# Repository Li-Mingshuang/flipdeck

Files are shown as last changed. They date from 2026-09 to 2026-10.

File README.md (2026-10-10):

# flipdeck —— 让手机变掌机的翻盖手柄壳（可翻转托盘）

```
翻开 = 3DS 形态：手机当上屏，下面是实体摇杆 + 按键
合上 = 普通手机：托盘翻 180°，手机屏幕朝上，按键被盖住
```

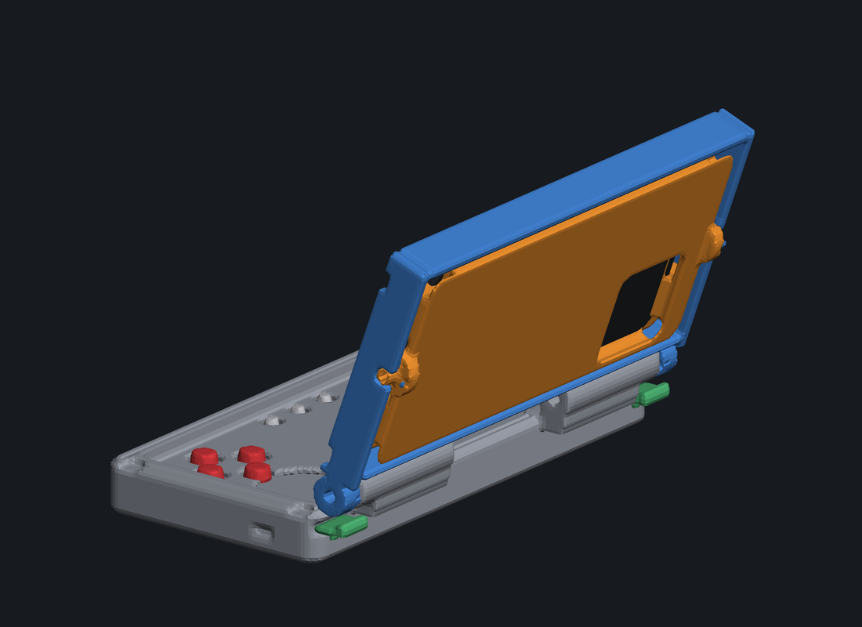
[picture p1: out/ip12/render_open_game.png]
展开游戏形态






**👉 [在线 3D 交互演示](https://li-mingshuang.github.io/flipdeck/)** —— 拖动看三种形态、拉滑块看托盘翻转、**还能直接用键盘玩手机屏幕上那个小游戏**（按哪个键，3D 模型上对应的键帽就按下去、摇杆就跟着摆）。

---

## 这是什么

一个**参数化 3D 结构方案**：给 iPhone 12（以及所有 ≤157×71.5mm 的 6.1"~6.3" 非 Max 机型）做的翻盖手柄壳。核心是一个**双平行轴机构**：

| 轴 | 位置 | 作用 |
|---|---|---|
| 合盖轴 θ | 后缘 | 翻开 / 合上，110° 是游戏角 |
| 托盘翻转轴 φ | 盖框内中线（沿 X） | 把手机连托盘翻 180°，屏幕从朝内变朝外 |

三种形态，一个动作切换：

| 形态 | θ / φ | 效果 |
|---|---|---|
| 展开游戏 | 110° / 0° | 手机当上屏（屏幕朝玩家），底座是摇杆 + 按键 |
| 合盖收纳 | 0° / 0° | 手机屏朝内被盖包住，按键也朝内，全保护 |
| 手机模式 | 0° / 180° | 手机屏朝上露出，按键被盖盖住，直接当普通手机用 |

## 三个关键设计（也是这个形态能成立的原因）

1. **托盘轴放在托盘板的中面上** → 翻转 180° 后托盘仍占同一层空间，只有手机从盖内侧换到盖外侧。否则要么盖变厚，要么合盖时手机撞底座。
   托盘还带一圈 **7.4mm 围边**（比手机屏幕高 0.7mm）：φ=0 时朝内、φ=180 时朝外，所以**两个方向手机都是"嵌"在托盘里的**，不会出现"一整块贴在框背面的板砖"。围边在 ±X 两端各开一个手指缺口方便取手机；围边留在托盘 160×74.5 轮廓内，翻转扫掠半径 37.85mm（横梁在 39mm，仍留 1.15mm）。
2. **铰链凸耳全部走左右两侧**（`|x| ∈ [80, 88.5]`）→ 托盘/手机翻转时扫出半径 37.9mm 的圆，盖的中间区域不能有任何腹板。（第一版腹板在中间，直接被扫掠圆撞掉，是靠数值检查抓出来的。）
3. **控制件全部沉进井里** → 合盖时手机屏幕的平面就是底座顶面，所以摇杆要沉进口袋、键帽要嵌进孔里（现在净空 3.5mm）。

## 已验证的东西（不是嘴上说说）

所有几何都是 SDF 参数化建模 + 数值验证，`python build.py` 一键复现：

| 检查 | 结果 |
|---|---|
| 9 个打印件网格 | **全部水密**（边界边 0、非流形边 0），直接可切片 |
| 13 项装配姿态间隙 | **全部无干涉** |
| 托盘翻转全程扫描（φ 0→180 每 10°） | 最坏 **+0.15mm**（就是 Ø6 轴颈在 Ø6.3 轴承孔里的设计间隙） |
| 合盖游戏位：手机屏幕 ↔ 最高控制件 | **+2.5mm** 净空 |
| 合盖手机模式：deck ↔ 手机 | **+8.8mm** |
| 整机厚度 | 合盖游戏 **34.1mm**；手机模式 **42.4mm**；**拔掉底座当日常壳 22.5mm** |

**日常模式**：拧下铰链的 M4 螺杆 → 取下带按键的底座 → 剩下盖框 + 托盘 + 手机 = **22.5mm 厚**的保护壳，屏幕朝上正常用。这是这个结构天然的"两用"方式，不需要额外零件（建议用 M4 手拧螺钉或插销，方便随时拆装）。

<details>
<summary>过程中修掉的真问题（点开看）</summary>

- 间隙检测公式用 `min(dA+dB)` 会**假阳性** → 改用 `min max(dA, dB)`
- 托盘位姿写成 `R·p + pivot` 会让托盘整体平移 51mm，导致 φ=180° 的所有检查数字全是假的
- 密封条槽外缘与外壳上收边在圆角处相交 → 会切出 0.3mm 薄片（已改成同心内缩，并写进断言）
- 体素网格化时零件平面正好落在采样平面上会产生歧义单元 → 非流形边；加"自动搜索采样相位"后 9 件全水密
- 画 PCB 时发现 ABXY 上排 / 十字键上臂的开关焊盘压进摇杆口袋的孔里 → 按键簇前移 3mm

</details>

## 快速开始（做一台能玩的原型）

| 步 | 做什么 | 花费 |
|---|---|---|
| 1 | **打印**：先只打 `cradle.stl`（首件验手机），再打 `deck` + `lid` | ¥30–60 起（代打） |
| 2 | **买件**：ESP32-S3 SuperMini + 2×摇杆模块 + 11 个 6×6×2.0 贴片开关 + 五金 | ~¥80–140 |
| 3 | **刷固件**：`firmware/flipdeck_gamepad/flipdeck_gamepad.ino`（Arduino IDE，改引脚即可） | ¥0 |
| 4 | 焊线 → 装壳 → 手机蓝牙配对 `flipdeck` → 开玩 | ¥0 |

- 打印下单话术 + 首件检查单：**[ORDER_KIT.md](ORDER_KIT.md)**（可直接复制给代打）
- 采购清单 / 引脚表 / 接线 / 固件说明：**[ELECTRONICS.md](ELECTRONICS.md)**、**[firmware/README.md](firmware/README.md)**
- 打印参数 / 装配顺序 / 分期计划 / 风险：**[DIY_GUIDE.md](DIY_GUIDE.md)**
- 进度、决策记录、升级待办：**[PROGRESS.md](PROGRESS.md)**

> **不需要画 PCB**：摇杆直接拧进底座（口袋里有 Ø28 分布圆的 M2 自攻孔），主控拧在底座的 PCB 柱上，11 个开关用打印的开关架定位（`switch_frame.stl`）。

## 在线 3D 演示

- 线上：<https://li-mingshuang.github.io/flipdeck/>（GitHub Pages，源 = `docs/`）
- 本地：

```bash
python -m http.server 8010
# 浏览器打开 http://127.0.0.1:8010/web/flipdeck_viewer.html
```

演示页是**零依赖**的（自己写的 WebGL 渲染器，不用 CDN）：拖滑块改 θ/φ、一键三形态、播放翻转动画、隐藏部件看内部、**日常模式一键看**（拔掉底座的样子）、换屏幕内容（可玩的游戏 / 主屏幕 / 你自己的图 / 灭屏）、CRT 扫描线滤镜。
**键盘能直接玩屏幕里的游戏**（两套：横版跑酷 + 伪 3D 赛车），同时 3D 模型上的键帽会按下去、十字键会跷、摇杆会摆；鼠标也能直接拖摇杆帽。
机构常数由 `web/public_params.json`（`web_export.py` 生成）注入，页面不会和 CAD 参数漂移；矩阵数学用 `web/verify_matrix.js` 与 Python 的 `poses.pose` 对过答案，四个姿态偏差 ≤0.0005mm。

## 🏆 排行榜 Top 10

> 在演示页里玩完小游戏（**跑酷 / 俄罗斯方块 / 打砖块 / 贪吃蛇 / Flappy**），点「提交成绩」会开一个预填好的 GitHub Issue；Actions 自动汇总到这里，也会画在演示页的手机屏幕上（屏幕下拉框选「🏆 排行榜（实时）」）。同一玩家每款游戏只记最好成绩。

<!-- LEADERBOARD:BEGIN -->
## 🎮 跑酷（`run`）

_还没有成绩 —— 来占个第一？_

## 🎮 俄罗斯方块（`tetris`）

_还没有成绩 —— 来占个第一？_

## 🎮 打砖块（`break`）

_还没有成绩 —— 来占个第一？_

## 🎮 贪吃蛇（`snake`）

_还没有成绩 —— 来占个第一？_

## 🎮 Flappy（`flappy`）

_还没有成绩 —— 来占个第一？_

_最后更新：2026-10-10 09:51（UTC）_
<!-- LEADERBOARD:END -->

## 模块化：换个底座就变形态

**铰链接口就是模块标准**（铰链销孔、凸耳位置、贴合面高度 19mm、磁铁位、密封槽都固定不变）。拔掉 M4 销 → 取下底座 → 换上另一个底座 → 插回销，10 秒完成；盖子、托盘、手机全都不用动。

| 底座 | 内容 | 用途 |
|---|---|---|
| `deck`（手柄底座） | 2 摇杆 + 11 按键 + 打印开关架 | 玩游戏 |
| `deck_keyboard`（键盘底座） | 一个**买来的迷你蓝牙键盘模块**（约 150×60×7.5mm，自带电池/蓝牙/充电口）的舱位 | **vibecoding**：手机在上盖当屏幕、键盘在下座 = 迷你笔记本 |
| 不装底座（日常） | 只剩盖框 + 托盘 + 手机 | 当普通保护壳（22.5mm 厚） |

键盘底座设计要点：舱体 152.4×62.4，模块放进去后**键面比边缘低 0.5mm**；前缘 0.8mm 挡边防倒置掉出；左侧壁开 14×6 口给模块插线充电；底部掏空省料。不需要触摸板（手机屏幕本身就是触摸屏），也不需要自研电路（键盘模块自带 BLE）—— **只需要打印一个底座**。

演示页里点「底座：手柄 / 键盘」可以直接切换看两种形态。

## 仓库结构

```
flipdeck-cad/
├─ flipdeck/            内核：params(参数) sdf(SDF内核) parts(零件) poses(位姿+间隙检查)
│                       meshlib(SDF→水密网格/STL) render(纯 numpy 软件渲染器)
├─ firmware/            ESP32-S3 BLE 手柄固件 + 烧录/标定说明
├─ web/                 交互式 3D 演示（WebGL，零依赖）+ 轻量 STL
├─ docs/                GitHub Pages（= web 的打包产物，由 make_docs.py 生成）
├─ out/stl/             **9 个打印件 STL**（全部水密）
├─ out/ip12/            iPhone 12 版渲染图（含 contact_sheet 总览拼图）
├─ out/pcb/             PCB 板框（DXF/SVG/PNG）+ 板级自检报告
├─ build.py             SDF→网格→STL + 渲染 + 报告（一键复现）
├─ check_poses.py       装配干涉检查
├─ pcb_outline.py       板框生成 + 板级自检
├─ web/verify_*.js      **没浏览器也能验证网页**（见下）
├─ web_export.py        导出网页用轻量 STL
├─ make_docs.py         生成 docs/（Pages）
├─ status.py            刷新 PROGRESS.md 的状态块
└─ ORDER_KIT.md / DIY_GUIDE.md / ELECTRONICS.md / PROGRESS.md / README.md
```

一键复现：`python build.py --render-dir ip12`（STL + 渲染 + 报告，约 6 分钟）。

**没浏览器也能验证网页**（本项目的所有前端改动都靠这套兜底，因为写代码的模型看不到画面）：
- `node web/verify_matrix.js` —— 机构矩阵与 Python 的 `poses.pose` 对答案（四个姿态偏差 ≤0.0005mm）
- `node web/verify_framing.js` —— 自动取景是否把所有零件完整包进画面（逐姿态算画面占用率）
- `node web/verify_runtime.js` —— 用 DOM/WebGL 桩把页面 JS 真跑一遍：逐条跑五个游戏、排行榜屏幕、姿态切换、提交按钮…并统计 `drawArrays` 次数，专门抓"打开就黑屏"这类加载期异常

## 换机型

`deck` 和 `lid` 的几何**完全不引用手机参数** —— 换手机只换托盘这一个件。托盘外廓 160×74.5 是"接口标准"，可装上限 **157 × 71.5mm**（6.1"~6.3" 非 Max 机型通用）；Pro Max / Plus 那档（77.6~78.1mm 宽）需要放大托盘并连锁放大盖框和底座。改 `flipdeck/params.py` 里的 `PHONES` 表 + `DEFAULT_PHONE`，然后 `python build.py` 即可，`sanity()` 会重新断言所有余量。

## 已知取舍

- **合盖手机模式相机会被盖挡住**（后摄贴着托盘板），要合盖拍照需要托盘轴偏心 + 开相机通孔
- **没有硬限位**：0°/110°/180° 靠凸点 + 摩擦自锁，防不住暴力过转
- **合盖 34–42mm 厚**：这是"合盖还要能当手机用"的物理代价；**日常用就拧下螺杆取走底座（22.5mm）**，想要更薄只能改架构（控制模块做成磁吸可拆）
- 手机固定靠托盘挡墙 + 沉台（正常使用不会掉），倒甩/装兜需要再加磁铁或 TPU 卡爪

## 许可证

- 代码（Python / 固件 / 网页）：**MIT**
- 硬件设计文件（STL、Pages 页面、生成的几何）：**CC BY 4.0**，署名注明 `flipdeck` 及本仓库链接

详见 [LICENSE](LICENSE)。

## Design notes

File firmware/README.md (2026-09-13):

# flipdeck 固件：烧录与标定

文件：`flipdeck_gamepad/flipdeck_gamepad.ino`（一个文件，Arduino IDE 直接打开）
作用：把底座的 2 个摇杆 + 11 个按键，做成标准 **BLE HID 游戏手柄**，iPhone / Android / PC 直接配对。

---

## 1. 装环境（一次性，15 分钟）

1. 装 **Arduino IDE 2.x**
2. 加 ESP32 开发板支持：`文件 → 首选项 → 附加开发板管理器网址` 填
   `https://espressif.github.io/arduino-esp32/package_esp32_index.json`
   → `工具 → 开发板 → 开发板管理器` 搜 `esp32` 安装 **2.0.x（推荐 2.0.17）**
   > ⚠️ **别用 3.x**：BLE API 变过，`ESP32 BLE Gamepad` 库在 3.x 上大概率编不过。
3. 装库：`工具 → 管理库` 搜 **ESP32 BLE Gamepad**（作者 lemmingDev）安装
   （装不上就从 GitHub 下 ZIP，用"从 ZIP 安装库"）

## 2. 烧录

1. 打开 `flipdeck_gamepad.ino`
2. 开发板选 **ESP32S3 Dev Module**；`USB CDC On Boot = Enabled`（不然串口没输出）
3. USB 插上，选对应串口 → 点上传
4. 串口监视器 115200，应看到：
   ```
   [flipdeck] booting ...
   [flipdeck] 标定摇杆中点：请松手
   [flipdeck] center  L=(2043,2051)  R=(2038,2049)
   [flipdeck] BLE name = flipdeck，等待配对…
   ```

## 3. 配对

- **iPhone 12**：`设置 → 蓝牙` → 找到 **flipdeck** → 点连接（会显示成"游戏手柄"）
- 验证：装个手柄测试 App（或直接在 Delta 模拟器里绑定按键）
- 连不上时：蓝牙里"忽略此设备"，开发板断电重上；iOS 会缓存旧的 BLE 设备名

## 4. 标定（拿到实物后做一次，5 分钟）

固件默认会在**开机时自动取摇杆中点**（开机那一秒别碰摇杆）。上下限和方向按需要微调：

1. 把 `#define DEBUG_SERIAL 1`，重新烧录，串口会每 200ms 打印原始值：
   ```
   raw LX=2043 LY=2051 RX=2038 RY=2049 | hat=0 | A=0 B=0 X=0 Y=0
   ```
2. 把摇杆推到底，记下 **最小/最大原始值**，改这两行：
   ```c
   #define ADC_MIN_RAW   200     // 推到底的最小值（比实测再往里留 50~100 更稳）
   #define ADC_MAX_RAW   3900    // 推到底的最大值
   ```
3. 方向反了 → 改 `INVERT_LX / LY / RX / RY`（左右反了改 X，上下反了改 Y）
4. 中心抖/漂 → 加大 `DEADZONE_PCT`（默认 6）或加大 `FILTER_SHIFT`（默认 2）
5. 都调好后把 `DEBUG_SERIAL` 改回 0，重新烧录

## 5. 按键对应关系（想换布局改配置区）

| 底座上的键 | GPIO | HID 编号 |
|---|---|---|
| A / B / X / Y | 6 / 7 / 8 / 9 | 1 / 2 / 3 / 4 |
| 十字键 | 12 / 13 / 14 / 15（上/下/左/右） | 帽子开关（Hat），不是独立按键 |
| Select / Start / Home | 17 / 16 / 18 | 9 / 10 / 13 |
| L1 / R1（肩键） | 21 / 38 | 5 / 6 |
| L3 / R3（摇杆按下） | 39 / 40 | 11 / 12 |
| 左摇杆 X / Y | 1 / 2 | 左摇杆轴 |
| 右摇杆 X / Y | 3 / 4 | 右摇杆轴 |
| 电池采样（可选） | 11 | 需分压 100k/100k，`REPORT_BATTERY 1` 才启用 |

> 日式手感（A/B 对调、X/Y 对调）→ 只改 `BTN_A`/`BTN_B`/`BTN_X`/`BTN_Y` 四个数字。
> 十字键用**帽子开关**上报（iOS 上游戏识别最正常）；如果你的游戏把十字键当按钮（1/2/3/4 那类），告诉我，我把 4 个开关改成独立按键上报。

## 6. 常见编译/烧录问题

| 现象 | 原因 / 处理 |
|---|---|
| `setAxes` 参数个数不对 | 库版本差异：把 `AXES_API` 改成 `6`（旧版没有 rudder），或按文件里注释改成 `setLeftThumb/setRightThumb/setHat1` |
| `setBatteryLevel` 未定义 | 老库没有这方法 → 保持 `REPORT_BATTERY 0` |
| BLE 库编译报 `NimBLE`/`BLEDevice` 相关错 | 开发板核心是 3.x → 降到 2.0.17 |
| 上传卡在 `Connecting...` | 按住 BOOT 再点上传；或换根数据线（很多线只能充电） |
| 串口没输出 | `USB CDC On Boot` 没开 |
| 配对了但游戏不认 | 先用测试 App 确认手柄在线；游戏本身不支持手柄的话，换有线也没用 |
| 摇杆一直往一边跑 | 中点没标定好 → 重开一次（开机时松手），或手动改 `ADC_CENTER_RAW` |

## 7. 接线对照（焊之前对一遍）

```
摇杆模块 5 针：VCC→3V3   GND→GND   X→对应 ADC 脚   Y→对应 ADC 脚   SW→L3/R3 脚
11 个开关    ：一端→GPIO，另一端→公共 GND（开关架上的横向总线槽就是干这个的）
主控供电     ：USB-C（原型阶段直接插线玩）；后期接锂电池 + TP4056
VBAT 采样（可选）：电池正极 → 100k → GPIO11 → 100k → GND
```

> 引脚表与 `ELECTRONICS.md` §7 一致，两边同时改就不会错。

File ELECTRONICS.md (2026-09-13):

# flipdeck 电子方案：能买现成吗？怎么装？

> 一句话回答：**电路全部能买现成的，一个零件都不用自己设计**；只有"翻转手柄壳"这个结构没有现成的（那就是我们做的）。
> 你的机器是 **iPhone 12（Lightning 口）**，所以只能走**蓝牙 BLE**，有线 USB 这条最省事的路走不通（下详）。

---

## 1. 哪些能买现成

| 环节 | 现成度 | 说明 |
|---|---|---|
| 翻转壳本体 | ✗ 没有 | 这就是本项目做的东西（STL 已出） |
| 主控 | ✔ 完全现成 | ESP32-S3 / nRF52840 开发板，¥25–70，BLE HID 手柄固件是开源的 |
| 摇杆 | ✔ 完全现成 | 现成的摇杆模块（碳膜或霍尔），带排线，¥5–15/个 |
| 按键 | ✔ 完全现成 | 贴片/插件轻触开关，¥0.1–0.5/个 |
| 电池 + 充电 | ✔ 完全现成 | 3.7V 软包 + TP4056/IP5306 充电小板，¥25–40 |
| 磁铁 / 螺丝 / 泡棉 | ✔ 完全现成 | 淘宝任意 |
| PCB | ⭕ 可以不打 | 第一版**飞线/杜邦线**就能跑通；要打板的话板框我已经生成好 |
| 固件 | ✔ 现成开源 | `ESP32-BLE-Gamepad`（lemmingDev）等，改改引脚映射即可 |

**完全可以"零电路设计"做出第一台原型**：开发板 + 摇杆模块 + 开关 + 电池，用线连起来塞进壳里。

## 2. 四条路线（按"省事 → 折腾"排）

| 路线 | 买什么 | 成本 | 说明 |
|---|---|---|---|
| **0：验证游戏认不认手柄** | 你已有的蓝牙手柄（没有就买一个 —— 反正后面能当供体） | ¥0–100 | 测的是"**游戏/模拟器认不认手柄**"，跟蓝牙/有线无关。已有手柄或已知支持 → **直接跳过** |
| **1：拆蓝牙手柄当供体（推荐原型走这条）** | 一个便宜的蓝牙手柄 ¥60–100 | **最低** | **iOS 原生支持标准蓝牙手柄（Xbox/PS4/PS5/Switch Pro），不需要 MFi**。拆出它的主板/摇杆/电池/充电口/电源开关全用上，你只要把 11 个开关焊到它的按键矩阵（万用表量行列）。**不用写固件、不用转接头、结构不用改** |
| **2：ESP32-S3 自建** | SuperMini + 摇杆模块 ×2 + 开关 + 电池 + 充电板 | ¥100–150 | 灵活可控，但要改固件引脚映射。适合供体摇杆尺寸不合适、或想完全自己掌控时 |
| **3：打板集成** | 上面那些 + 自己画板（嘉立创 5 片 ¥5–30） | +¥30 | 用我给的 DXF 板框。想批量/想好看再走 |

> ⚠️ 路线 1 唯一要注意的：**供体的摇杆尺寸不一定正好塞进我设计的 Ø32 口袋**。选定供体后量一下摇杆模块的直径和高度告诉我，我改口袋直径或出个转接环（几分钟的事）。

### 两条路线的真实成本与取舍（国内价）

| | 实际花费 | 要逆向按键矩阵 | 要刷固件 | 摇杆要不要挪位置 |
|---|---|---|---|---|
| **拆供体手柄** | **¥50–90**（带 2 摇杆的拉伸蓝牙手柄就这个价） | ✔ 万用表量行列 | ✗ | ✔ 从供体板上拆下来焊线 |
| **散件自建**（摇杆模块 + ESP32） | **¥40–70** | ✗ | ✔（代码我可以给） | ✗ 现成模块直接塞口袋 |

两条路总价接近：**会动烙铁的话，自建其实更干净**（不用猜矩阵、摇杆直接买现成的）；供体路线唯一的优势是省掉固件。

**挑供体的三个要点**：
1. 页面**明确写"支持 iOS/苹果"**（只写"安卓专用"的有可能是私有协议，iPhone 认不到）；
2. 确认是**真摇杆**（可变输出），不是 8 向"假摇杆"；
3. 优先选**螺丝可拆**的（不是全卡扣+胶），方便拆件。

**建议执行顺序**：先买供体 → 当手柄连 iPhone 验证游戏支持（无论如何都要做）→ 拆开看摇杆好不好移 → 好移走供体路线，不好移我出固件走自建。

## 3. Lightning 有线到底行不行

**能，但都不是"直插"**。三条路：

| 方式 | 怎么做 | 延迟 | 代价 |
|---|---|---|---|
| **A. 相机转接头** | Lightning→USB 相机转接头，**有线形态的短辫子（Lightning 公 → USB-A 母，10–15cm）¥25–70**；主控以 **USB HID 设备**身份出现（ESP32-S3 支持 TinyUSB） | 2–8ms | 转接头是个挂件；而且**换形态必须拔线**（见下） |
|  | ⚠️ 买的时候必须挑**明确写"支持 iOS OTG/键盘/游戏手柄"**的：iOS 当 USB 主机要 Apple 认证芯片，几块钱那种一般只能充电、认不到设备 | | |
| **B. 拆 MFi 手柄取板** | 买一个便宜的 MFi 认证手柄，把它的主板 + Lightning 头留用，把按键点焊出来接你的开关 | 2–8ms | ¥100–300，要逆向它的按键矩阵；但这是"真·直插"，不用转接头 |
| **C. 自己做 Lightning 直插** | 需要 Apple MFi 授权 + 认证芯片 | — | 个人 DIY 基本拿不到 |

**我的建议**：默认 **v1 蓝牙**，理由只有一个 —— 有线必须过线/拔线（见下），而蓝牙插上就玩。**但如果你优先级是低延迟，有线完全可行**，按 A 或 B 走，我再改结构配合（deck 前端加短线舱 + 拔插位，线从底座前缘走到手机 Lightning 口，换形态时拔掉）。真要有线，**B（拆 MFi 手柄）比 A 干净**：直接一根 Lightning 辫子线，不用挂转接头。

**为什么有线在这个结构上别扭**：托盘要转 180° 换形态，而我把设计做成"三根轴里一根线都不走"就是为了避免过线。有线方案下，每次切换"游戏 ↔ 手机模式"都得先拔线。这条不是做不到，是"多一个动作 + 多一根线"。

其余两点约束不变：
2. **iOS 认 BLE HID 手柄**：iOS 13+ 原生支持；Delta、PPSSPP、RetroArch 等模拟器支持很好；部分原生游戏也支持，但**不是所有游戏** → 所以先做"0 路线"验证。
3. **延迟**：BLE 约 10–25ms；音游、格斗连招、竞技 FPS 会感觉出来。

## 4. 采购清单（可直接照着搜）

### 主控（选一个）
| 搜索词 | 关键尺寸 | 参考价 |
|---|---|---|
| `ESP32-S3 SuperMini 开发板` | 约 22.5 × 18 mm（**我按这个尺寸留的位置**） | ¥25–40 |
| `nRF52840 SuperMini` / `Adafruit Feather nRF52840` | 更小、功耗更低，贵一点 | ¥60–120 |

> 选它的理由：能跑 `ESP32-BLE-Gamepad` 这类开源固件，直接把自己伪装成蓝牙手柄；板子小、有 USB-C、能边充边用。

### 摇杆（选 2 个）
| 搜索词 | 关键尺寸 | 注意 |
|---|---|---|
| `PSV2000 摇杆模块` / `碳膜 摇杆模块 带排线` | 模块 ≤ Ø24，总高 ≤ 13mm | **首选碳膜**：托盘上有 MagSafe 磁环，霍尔可能漂移 |
| `霍尔摇杆模块`（要用就先测磁干扰） | 同上 | 手感好、不磨损，但要过 §9 的磁干扰测试 |

摇杆装在壳里的 Ø32 口袋里（口袋底 z=5.5），用 4×M2 自攻固定（分布圆 Ø28）。模块到主板的连线走 **5 针排线**（VCC/GND/X/Y/SW）。

### 开关（都选贴片或矮款）
| 用途 | 规格 | 数量 |
|---|---|---|
| ABXY | 6×6×**2.0mm** 贴片轻触（板面到顶面 2.0） | 4 |
| 十字键 | 6×6×2.0mm 贴片 | 4 |
| Start/Select/Home | 6×6×2.0mm 贴片 | 3 |
| 肩键 L/R | 6×6×2.5mm（装在后壁槽里，走线到主板） | 2 |

> ⚠️ 高度很关键：PCB 顶面在 z=8，内腔顶在 z=10.5 → **开关总高只能 2.0–2.5mm**。买长了塞不进去（或者要改 `params.py` 里的 `PCB_TOP`）。

### 电源
| 搜索词 | 规格 |
|---|---|
| `3.7V 锂电池 1500mAh 软包` | ≤ 60 × 50 × 5.5mm（板下空间 79×79×6.0，避开两个摇杆口袋） |
| `TP4056 充电模块 Type-C` 或 `IP5306` | 充电 + 保护；也可以直接用带充电管理的开发板 |
| `JST-PH 2.0 插头` | 电池接口，别直接焊电池线 |

### 结构/五金（同 `DIY_GUIDE.md`）
M4×150 螺杆 + M4 螺母×2 + Ø10×1.0 尼龙垫圈×4（合盖轴）；M3×16 + M3 方螺母 + Ø10×0.8 尼龙垫圈×2（托盘轴）；Ø8×2 磁铁×8；MagSafe 磁环×1；1.5mm 泡棉条。

## 5. 不打 PCB 也能做：打印开关架（推荐原型走这条）

**摇杆和主控本来就不需要板子**：

| 件 | 怎么固定 | 需要板吗 |
|---|---|---|
| 摇杆模块 ×2 | 直接拧进底座的摇杆口袋（口袋里已有 Ø28 分布圆的 4×M2 自攻底孔） | ✗ 不用 |
| 主控开发板 | 拧在底座的 **4 个 PCB 柱**上（`(±40,±30)`，Ø4.6 柱 + Ø1.9 自攻孔），或用双面胶/扎带 | ✗ 不用 |
| **11 个开关** | **唯一需要"定位载体"的东西** —— 用新给你的打印开关架 | ✗ 不用画板 |

**`out/stl/switch_frame.stl`（新）** 就是那个载体，等于"用打印件替代 PCB"：

```
外形      168 × 76 × 1.8mm，和 PCB 板框完全同一套几何
安装孔    4 × Ø2.4 @ (±40, ±30)   ← 和 PCB 一样拧在底座柱上
摇杆让位  2 × Ø33 通孔 @ (±56, +14)
开关窗口  11 个 6.6 × 6.6mm，顶部两侧各 0.3mm 卡扣凸台（开关从下方压进去就被压住）
走线槽    每个窗口到底面的 2mm 槽 + 一条横向总线槽，细线塞进去不外露
```

用法：把 11 个 6×6×2.0 贴片开关从下面压进窗口 → 每个开关一个信号脚焊一根细线、另一个脚全部并到公共 GND（走线槽里）→ 细线接到主控的对应 GPIO → 整个开关架拧在底座上，键帽就直接压在开关上。耗材约 8g。

**一个硬约束**：内腔净高只有 8.5mm，开关架顶面在 z=9.8 → **只能用 2.0mm 高的贴片开关**（手焊 4 个焊盘，能焊但要有耐心）。
如果你想用便宜的**插件**开关（4.3–5mm 高），就得把开关架/板子放低到 z=5.5 —— 那样电池空间从 6mm 掉到 3mm，得换薄电池。要做这个变体我改一个参数重出就行。

什么时候才需要真 PCB：想要干净、想批量、想上贴片机、或者想把充电/电量计/指示灯都集成进去。板框已经生成好，直接下单即可。

## 6. PCB 板框（已生成好）

| 文件 | 用途 |
|---|---|
| `out/pcb/flipdeck_pcb_outline.dxf` | **打板就用它**：导入立创EDA/KiCad，外轮廓放 `Edge.Cuts` 层 |
| `out/pcb/flipdeck_pcb_outline.svg` | 矢量预览（带标注） |
| `out/pcb/flipdeck_pcb_layout.png` | 位号布局预览图 |
| `out/pcb/PCB_FIT_REPORT.md` | 板级自检报告（见 §8；打印开关架用的是同一套几何，同样适用） |

板框参数（全部由壳体几何推导，改壳自动跟着变）：

```
外形        168 × 76 mm，四角 R5，厚 1.6mm
摇杆让位    2 × Ø33 通孔 @ (±56, +14)      ← 必须开孔，摇杆口袋比板面深
安装孔      4 × Ø2.4 @ (±40, ±30)          ← 对准 deck 里的 PCB 柱
USB-C       左边缘，中心 y=-6，母座贴板底朝下（对上壳侧壁 10×4.2 的开孔）
电源拨钮    右边缘 y=+22（对上壳侧壁的 7×3 开孔）
主控        22.5 × 18 模块 @ (0, +18)，天线朝 +y，板前缘留 6mm 不铺铜
摇杆插座    2 × 5pin @ (±30, +14)
电池        板下 z 2~7.5，可用 79 × 79 × 6.0mm（建议软包 ≤60×50×5.5）
```

打板订单参数：**双面、1.6mm、无特殊工艺、绿油**（嘉立创 5 片 ¥5–30）。不需要阻抗控制。

## 7. 引脚表（ESP32-S3）

按键全部用"GPIO → GND + 内部上拉"，摇杆走 ADC。

| 功能 | GPIO | 说明 |
|---|---|---|
| 左摇杆 X / Y | **1 / 2** | ADC1，5 针排线 |
| 右摇杆 X / Y | **3 / 4** | ADC1 |
| A B X Y | 6 / 7 / 8 / 9 | |
| 十字 上/下/左/右 | 12 / 13 / 14 / 15 | |
| Start / Select / Home | 16 / 17 / 18 | |
| 左肩 L1 / 右肩 R1 | 21 / 38 | |
| 左摇杆按下 L3 / 右摇杆按下 R3 | 39 / 40 | 摇杆模块第 5 针（SW） |
| 电池电压采样 | 11 | ADC2，串 100k/100k 分压到 3V3 量程 |
| 充电状态（可选） | 41 | 接充电板 CHRG 脚 |
| I2C（可选：OLED/电量计） | 47(SDA) / 48(SCL) | |
| **别用** | 0(BOOT)、19/20(USB D±)、26–37(Flash/PSRAM)、45/46(strapping) | |

接线要点：
- 摇杆模块：`VCC→3V3、GND→GND、X/Y→对应 ADC、SW→对应 GPIO`；**X/Y 中点电压应约 1.65V**，如果偏移太多再改固件的中心校准。
- 每个按键：一端接 GPIO，一端接 GND（`INPUT_PULLUP`，按下为低）。
- 电池：**必须经保护板**；VBAT 采样串分压，别把 4.2V 直接怼进 ADC（S3 的 ADC 量程 3.3V）。
- 肩键开关在壳的后壁槽里，用两根细线引回主板（或者背一块小转接板）。

## 8. 板级自检（已跑，全过）

```
✔ 板宽/深 168 × 76（内腔 170 × 79，单边留 1.0mm）
✔ 板厚+开关 1.6 + 2.0 = 3.6mm ≤ 内腔净高 8.5mm
✔ 开关焊盘全在板内
✔ 焊盘到摇杆让位圆最近 +0.50mm（就是 ABXY 上排那颗，见下）
✔ 4× 安装孔与 deck 的 PCB 柱同心
✔ 安装孔到让位圆 +6.13mm
✔ USB-C 对位（y=-6，对壳侧孔）
✔ 主控模块位置不压开关/让位圆
✔ 电池空间 79 × 79 × 6.0mm
```

> 画板时发现并已修掉的冲突：原设计 ABXY / 十字键的中心在 y=−14，**上排按键的焊盘正好压进摇杆口袋的 Ø32 孔里**（那里没有板子可焊）。我把两个按键簇整体前移 3mm（y=−17）——这是打印壳体唯一的改动，已重新出 STL 并重新验证（`out/stl/deck.stl`、`cap_dpad.stl`、`caps_abxy.stl` 已更新）。
> 顺便修了键帽：原来键帽浮在井底上方、中心柱有 6mm 长；现在键帽帽体嵌进 Ø10.4 孔（底面 z=10.4，正好压在 2mm 开关上）。

## 9. 动手顺序（照这个走，别跳）

1. **先验证需求**（0 路线）：买一个现成蓝牙手柄连 iPhone 12，确认你要玩的游戏认手柄、延迟能接受。
2. **桌面搭电路**：开发板 + 2 摇杆 + 开关，**先不装进壳**，飞线连好，刷固件，连手机，把每个键都按一遍。
3. **磁干扰测试**（用霍尔摇杆才需要）：把 MagSafe 磁环贴近摇杆模块，看中点漂移多少；漂移大就换碳膜摇杆，或给磁铁加屏蔽片。
4. **装壳**：先装 deck 里的电子（摇杆口袋、按键、电池），确认开关高度对得上键帽（键帽底面 z=10.4，开关顶面应 ≈10.0）。
5. **再上盖**：合盖铰链、托盘轴、磁铁，按 `DIY_GUIDE.md` §5 走。
6. **手感调优**：摇杆死区/曲线、肩键行程、棘轮松紧。

## 10. 固件（现成的，改引脚就行）

- **ESP32-S3**：用 `ESP32-BLE-Gamepad`（Arduino，lemmingDev）。核心就三件事：
  1. `BleGamepad bleGamepad("flipdeck", "DIY", 100);` 起一个 BLE 手柄；
  2. 把 §7 的引脚映射写成 `pinMode(pin, INPUT_PULLUP)` + 读摇杆 ADC → `bleGamepad.setLeftThumb(x, y)`；
  3. 摇杆做**中心校准 + 死区**（±5%）和方向反转。
- 配对：iPhone 12 里"设置 → 蓝牙"，配对名会显示成游戏手柄。
- 想更省事也可以刷现成的 "ESP32 蓝牙手柄" 开源工程，只改引脚定义。

## 11. 我还能接着帮你做什么

- 把板框画成**完整的 PCB 布局**（元件坐标 + 丝印 + 走线建议），你导入立创EDA 就能直接下单；
- 出一份**固件骨架代码**（引脚映射 + 摇杆校准 + BLE HID 上报），直接能编译；
- 或者你先走 §9 的 1–2 步，把踩到的问题丢回来，我再改结构（比如开关高度、摇杆型号换了要改壳）。

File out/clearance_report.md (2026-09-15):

# 装配间隙报告

- 托盘接口标准 160.0×74.5×6.6（deck/lid 与机型无关）：可装最大 157.3 × 71.8 mm 的手机；当前机型挡墙 X 6.30 / Y 1.15 mm
-   各机型适配：iPhone 12 / 12 Pro ✔；iPhone 12 Pro Max ✘需 PLATE 164×81；iPhone 16 Pro ✔；iPhone 16 Pro Max ✘需 PLATE 166×80；iPhone 15 ✔；iPhone 17 ✔；Pixel 8 ✔
- lid 窗口 169.0 x 78.0；手机 146.7 x 71.5 -> X余量 11.15，Y余量 3.25
- 翻转扫掠半径 托盘 37.85 / 手机 37.12；到前梁 39.00、后梁 39.00 -> 最小余量 1.15mm
- 铰链轴线到托盘轴 51.2mm，凸耳半径 7.0 -> 距扫掠圆余量 6.38mm；凸耳 |x| ∈ (80.0, 88.5) vs 托盘板 |x|<= 80
- deck 后壁顶角到铰链轴线 8.60，凸耳半径 7.0 -> 余量 1.60mm
- 肩键顶端到铰链轴线 11.18 -> 余量 4.18mm
- 合盖游戏位：手机屏幕平面 z=19.0；摇杆帽顶约 z=16.5、键帽顶 z=15.4 -> 净空 2.5mm
- 开关焊盘到摇杆让位圆(Ø33) 最近 +0.50mm @ (56,-6)
- 密封条槽：外壁实体 1.50mm（需 >= 1.0）、槽宽 1.5、深 1.0；槽内缘距控制井 1.40mm
- 整机厚度：合盖游戏 34.1mm；合盖手机模式 42.4mm；展开游戏(θ=110°) 高 114mm × 深 132mm

| 场景 | 零件对 | θ | φ | 最小间隙 mm | 位置 |
|---|---|---|---|---|---|
| 合盖·游戏(收纳) | deck-lid | 0 | 0 | +0.00 | (-87, -39, 19) |
| 合盖·游戏(收纳) | deck-phone | 0 | 0 | +1.92 | (-68, -37, 20) |
| 合盖·游戏(收纳) | lid-cradle | 0 | 0 | +0.17 | (-89, 1, 32) |
| 展开·游戏 | deck-lid | 110 | 0 | +0.24 | (80, 49, 21) |
| 展开·游戏 | deck-cradle | 110 | 0 | +6.77 | (-74, 53, 36) |
| 展开·游戏 | deck-phone | 110 | 0 | +8.28 | (-62, 53, 37) |
| 合盖·手机模式 | deck-phone | 0 | 180 | +8.77 | (-63, 38, 29) |
| 合盖·手机模式 | deck-cradle | 0 | 180 | +3.92 | (-85, -3, 21) |
| 合盖·手机模式 | lid-cradle | 0 | 180 | +0.16 | (-89, -2, 28) |
| 翻转扫描 θ=110 | lid-cradle | 110 | 0 | +0.15 | (-88, 69, 75) |
| 翻转扫描 θ=110 | lid-cradle | 110 | 10 | +0.16 | (-89, 73, 75) |
| 翻转扫描 θ=110 | lid-cradle | 110 | 20 | +0.16 | (84, 71, 75) |
| 翻转扫描 θ=110 | lid-cradle | 110 | 30 | +0.16 | (84, 69, 75) |
| 翻转扫描 θ=110 | lid-cradle | 110 | 40 | +0.15 | (-88, 74, 72) |
| 翻转扫描 θ=110 | lid-cradle | 110 | 50 | +0.16 | (84, 74, 71) |
| 翻转扫描 θ=110 | lid-cradle | 110 | 60 | +0.15 | (84, 74, 71) |
| 翻转扫描 θ=110 | lid-cradle | 110 | 70 | +0.16 | (-88, 73, 74) |
| 翻转扫描 θ=110 | lid-cradle | 110 | 80 | +0.16 | (84, 69, 75) |
| 翻转扫描 θ=110 | lid-cradle | 110 | 90 | +0.16 | (84, 74, 71) |
| 翻转扫描 θ=110 | lid-cradle | 110 | 100 | +0.15 | (-88, 74, 72) |
| 翻转扫描 θ=110 | lid-cradle | 110 | 110 | +0.16 | (84, 69, 75) |
| 翻转扫描 θ=110 | lid-cradle | 110 | 120 | +0.20 | (84, 77, 70) |
| 翻转扫描 θ=110 | lid-cradle | 110 | 130 | +0.16 | (-88, 68, 72) |
| 翻转扫描 θ=110 | lid-cradle | 110 | 140 | +0.15 | (84, 74, 72) |
| 翻转扫描 θ=110 | lid-cradle | 110 | 150 | +0.15 | (84, 73, 74) |
| 翻转扫描 θ=110 | lid-cradle | 110 | 160 | +0.16 | (-88, 71, 69) |
| 翻转扫描 θ=110 | lid-cradle | 110 | 170 | +0.15 | (-88, 69, 70) |
| 翻转扫描 θ=110 | lid-cradle | 110 | 180 | +0.16 | (84, 68, 72) |
| 翻转扫描(全部件最坏) | lid-cradle | 110 | 0 | +0.15 | (-88, 69, 75) |
| 手机模式合盖过程 | deck-phone | 30 | 180 | +9.68 | (-61, 43, 36) |
| 手机模式合盖过程 | deck-phone | 60 | 180 | +11.81 | (-69, 49, 39) |
| 手机模式合盖过程 | deck-phone | 90 | 180 | +9.51 | (-66, 52, 37) |

结论：全部姿态无干涉

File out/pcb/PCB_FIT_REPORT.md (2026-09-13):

# PCB 板框与装配自检

机壳：iPhone 12 / 12 Pro

| 项目 | 实测 | 要求 | 结果 |
|---|---|---|---|
| 板宽/深 | 168 × 76 | 内腔 170 × 79（留 ≥1.0mm） | ✔ |
| 板厚 + 开关高 | 1.6 + 2.0 = 3.6 | ≤ 内腔净高 8.5 | ✔ |
| 开关焊盘在板内 | 全部 | |x|≤83.5, |y|≤37.5 | ✔ |
| 焊盘到摇杆让位圆(最近 ABXY(56,-6)) | +0.50mm | ≥ 0.5mm | ✔ |
| 4× 安装孔对准 deck 的 PCB 柱 | ((40.0, 30.0), (-40.0, 30.0), (40.0, -30.0), (-40.0, -30.0)) | 同心 Ø2.4 / 柱 Ø4.6 | ✔ |
| 安装孔到摇杆让位圆 | +6.13mm | ≥ 0.5mm | ✔ |
| USB-C 母座对位 | y=-6.0 (板底朝下) | deck 侧孔 y=-6.0 ±5.0, z=6.0 | ✔ |
| 主控模块位置净空 | 22.5×18.0 @ (0.0, 18.0) | 不压开关/让位圆 | ✔ |
| 板下电池可用空间 | 79 × 79 × 6.0 | 建议 ≤ 60 × 50 × 5.5 软包 | ✔ |

结论：全部通过 ✔

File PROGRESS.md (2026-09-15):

# flipdeck 进度总表（活文档）

> **这份是入口文档。** 原则：**先把原型做出来，能简化的一律简化**；更好的方案全部记在
> §5「升级待办（以后再说）」，不阻塞原型。
>
> 下面的「当前状态」区块由 `python status.py` 从仓库真实状态生成，其余内容是手写的计划与决策记录。

<!-- AUTO:STATUS:BEGIN -->
### 当前状态（脚本自动生成：2026-09-15 12:34，运行 `python status.py` 刷新）

- 机型：**iPhone 12 / 12 Pro**（146.7 × 71.5 × 7.4 mm），已出全套 STL 与渲染
- 打印件：**10 件**，✔ 全部水密（边界边 0 / 非流形边 0 才算通过）
- 装配干涉：结论：全部姿态无干涉
- 板框/开关架自检：结论：全部通过 ✔
- 渲染图：`out/ip12/` 共 15 张（09-15 12:33）

**打印件明细（`out/stl/`）**：

| 零件 | 三角面 | 实体体积 cm³ | 水密 | STL |
|---|---|---|---|---|
| deck | 653092 | 120.5 | ✔ | `deck.stl` (32.7MB) |
| deck_keyboard | 666956 | 160.0 | ✔ | `deck_keyboard.stl` (33.3MB) |
| lid | 169784 | 29.3 | ✔ | `lid.stl` (8.5MB) |
| cradle | 271008 | 64.8 | ✔ | `cradle.stl` (13.6MB) |
| cap_dpad | 11664 | 2.3 | ✔ | `cap_dpad.stl` (0.6MB) |
| caps_abxy | 10784 | 1.3 | ✔ | `caps_abxy.stl` (0.5MB) |
| caps_small | 3072 | 0.2 | ✔ | `caps_small.stl` (0.2MB) |
| lever_l | 5452 | 0.7 | ✔ | `lever_l.stl` (0.3MB) |
| lever_r | 5452 | 0.7 | ✔ | `lever_r.stl` (0.3MB) |
| switch_frame | 188888 | 18.5 | ✔ | `switch_frame.stl` (9.4MB) |

**文档**：`PROGRESS.md`（本文，进度+计划+决策）、`README.md`（结构/尺寸/物料）、`DIY_GUIDE.md`（打印+装配+分期）、`ELECTRONICS.md`（采购+引脚表+固件）、`out/BUILD_NOTES.md`、`out/clearance_report.md`、`out/pcb/PCB_FIT_REPORT.md`

**一键复现**：`python build.py --render-dir ip12`（出 STL+渲染+报告，约 6 分钟）／`python check_poses.py`（只跑干涉，约 4 分钟）／`python pcb_outline.py`（板框+自检）／`python debug_slices.py`（剖面 ASCII 自检）／`python status.py`（刷新本文状态块）

<!-- AUTO:STATUS:END -->

---

## 1. 现在到哪一步了（一句话）

**结构设计已完成并验证 → 电子方案已定 → 下一步就是买件、打印、动手装配。**

- ✅ 机构（双平行轴：合盖 + 托盘翻转 180°）已定型，位置、间隙、翻转全程都做过数值验证
- ✅ 9 个打印件全部水密（边界边 0 / 非流形边 0），STL 可直接切片
- ✅ 底盘/盖框与机型无关，只有托盘随手机变（你的 iPhone 12 版已出好）
- ✅ 电子方案：**自建路线已定**（ESP32-S3 + 2 摇杆模块 + 11 开关 + 打印开关架），不需要画 PCB
- ✅ **固件已写完**：`firmware/flipdeck_gamepad/flipdeck_gamepad.ino`（+ 烧录/标定说明 `firmware/README.md`）
- ✅ **已开源发布**：<https://github.com/Li-Mingshuang/flipdeck>，在线 3D 演示 <https://li-mingshuang.github.io/flipdeck/>
- ✅ **交互式 3D 演示页**：`web/flipdeck_viewer.html`（零依赖 WebGL；可玩键盘小游戏、键帽/摇杆会动、CRT 滤镜）
- ✅ 采购清单、引脚表、装配顺序、分期计划、下单话术+首件检查单都写好了
- ⬜ 还差：**买件 → 打 0 期首件（只打托盘验手机）→ 焊线 → 刷固件 → 装电子 → 整机**（全是动手的活，没有设计阻塞）

## 2. 原型优先：简化后的最短路径

原型阶段砍掉一切非必需的东西，目标是**先让它动起来、能玩**：

| 期 | 做什么 | 打印 | 花费 | 通过标准 |
|---|---|---|---|---|
| **0** | 只打 `cradle`（11MB，~29g，3–4h） | 1 件 | ¥0 | 手机放进去贴平、相机凸台落进让位坑、挡墙不遮屏幕 |
| **1** | 打 `lid` + `deck` + `hinge_pin`，**0.28mm 层高、15% 填充、不装电子** | 3 件，~75g，6–8h | ¥0 | 托盘能在导轨里转、0°/110°/180° 有"咔"感、合盖顺畅、用纸片模拟控制高度确认不顶手机 |
| **2** | 电子**在桌面裸接**跑通（不装进壳）：主控 + 1 个摇杆 + 4 个键 + **刷固件** | 0 | ~¥70 | iPhone 12 蓝牙能连上手柄，模拟器里摇杆/按键全部响应，延迟可接受 |
| **3** | 电子装进底座（2 个摇杆 + 11 键 + 开关架），整机装配 | `switch_frame` + 键帽 + 杠杆 | +~¥60 | 合盖、翻转、换形态全部顺畅，能连续玩 |
| 4 | 手感调优（棘轮松紧、摇杆帽高、肩键行程） | 小件 | ¥0 | — |

**原型阶段刻意砍掉的东西**（都能后期加回来，见 §5）：
- ❌ 磁铁（MagSafe 环 + 合盖磁铁）→ **手机本来就靠托盘的沉台 + 1.2mm 挡墙卡住，直接放上去就行**，不用胶也不用磁铁（见下）
- ❌ 电池 + 充电板 → 2 期直接插 USB 供电（开发板自带 Type-C），省 ¥30 和一堆走线
- ❌ 泡棉密封条 → 合盖有轻微晃动不影响验证
- ❌ 肩键杠杆（先打也行，不打就把开关线引到后壁孔用指甲按）
- ❌ 完整 PCB → 用打印开关架替代（已出件）

**关于"手机怎么固定"（澄清）**：托盘本身就够用 ——
沉台深 0.8mm、四周挡墙高出手机背面约 1.3mm（游戏位）/ 0.7mm（手机位）、单边间隙 0.35mm。正常拿着玩、开盖、翻转、合盖，重力方向都是把手机压进托盘里，不会掉。
只有两种情况下需要加固：**倒过来甩**、或者**装兜里挤**。到那时再上磁铁（或打印 TPU 卡爪）就行，不影响现在的验证。
所以原型阶段：手机 = 直接放上去，零成本。

### 最短采购清单（原型版，¥60–150）

**首选路线：买一个便宜蓝牙手柄当"供体"拆件（¥50–90）** —— iOS 原生支持标准蓝牙手柄，**不需要 MFi**。拆出它的主板 / 摇杆 / 电池 / 充电口 / 电源开关全部用上，你只要把 11 个开关焊到它的按键矩阵（万用表量行列）。**不用写固件、不用转接头、结构不用改**。

| 件 | 搜索词 | 价 | 必需 |
|---|---|---|---|
| **供体手柄**（推荐） | 便宜蓝牙手柄（外形无所谓，反正是拆件） | ¥50–90 | ✔ 首选 |
| 或：主控 | `ESP32-S3 SuperMini`（想自己写固件走这条） | ¥25–40 | ⭕ 二选一 |
| 或：摇杆 | `碳膜摇杆模块 带排线` ×2（供体的摇杆能用就不用买） | ¥10–30 | ⭕ |
| 开关 | `6x6x2.0 贴片轻触开关` ×11 | ¥5–15 | ✔ |
| 铰链轴 | `M4 螺杆 150mm` + `M4 螺母` + `Ø10x1.0 尼龙垫圈` | ¥10–15 | ✔ |
| 托盘轴 | `M3x16 螺钉` + `M3 方螺母` + `Ø10x0.8 尼龙垫圈` | ¥8–12 | ✔ |
| 螺丝 | `M2 自攻螺丝` 若干（摇杆 8 颗） | ¥5 | ✔ |
| 线 | `30AWG 硅胶线` | ¥10 | ✔ |
| 磁铁 | `Ø8x2 圆磁铁` ×8 + `MagSafe 磁吸环` | ¥15–25 | ⭕ 可延后（托盘挡墙就够） |
| 电池 / 充电 | 软包 ≤60×50×5.5 + `TP4056` | ¥25–35 | ⭕ 供体自带就不用买 |

> **两条路线总价接近**：供体 ¥50–90（要逆向按键矩阵）vs 散件自建 ¥40–70（要刷固件，代码我给）。
> 会动烙铁的话自建更干净；供体路线唯一优势是省掉固件。挑供体三要点：页面明确写"支持 iOS"、真摇杆（不是 8 向假的）、螺丝可拆。详见 `ELECTRONICS.md` §2。
> ⚠️ 供体的摇杆不一定正好塞进 Ø32 口袋 —— 量一下直径/高度告诉我，我改口袋或出转接环。

> **那 ¥100 的手柄测试是测什么**：测的是"**你的游戏/模拟器认不认手柄**"，跟蓝牙还是有线**无关** —— iOS 上游戏对手柄的支持是系统/游戏层面的事，游戏不认手柄，插线也没用。所以：
> - 你**已经有**蓝牙手柄 → 直接拿它试，不用花钱（而且它可能就是你的供体）；
> - 你确定要玩的游戏（比如 Delta 模拟器里那些）本来就支持手柄 → 这步可以直接跳过；
> - 完全不确定 → 买个便宜的试一次，反正拆了当供体也不亏。
>
> **蓝牙 vs 有线**：有线延迟更低（2–8ms vs 10–25ms），但 Lightning 要有线得走相机转接头或拆一个 MFi 手柄取板，而且**换形态必须先拔线**（托盘要转 180°）。所以默认 v1 蓝牙；要低延迟优先，见 `ELECTRONICS.md` §3 —— 那条路我可以把结构改成"短线舱 + 拔插位"，你说一声就改。

## 3. 打印清单（现在就能切）

| 文件 | 件 | 什么时候打 |
|---|---|---|
| `out/stl/cradle.stl` | 托盘（**唯一与机型相关的件**） | 0 期，先打这个 |
| `out/stl/lid.stl` | 盖框 + 铰链凸耳 | 1 期 |
| `out/stl/deck.stl` | 控制底座（控制井/摇杆口袋/接口孔/PCB 柱） | 1 期 |
| `out/stl/hinge_pin.stl` | 销轴（**建议直接用 M4 螺杆，这件可不打**） | ⭕ |
| `out/stl/switch_frame.stl` | **打印开关架（替代 PCB）** | 3 期 |
| `out/stl/caps_abxy.stl` / `cap_dpad.stl` / `caps_small.stl` | 键帽 | 3 期 |
| `out/stl/lever_l.stl` / `lever_r.stl` | 肩键杠杆 | ⭕ 可延后 |

打印参数：PETG，0.4 喷嘴，3 圈壁。首件可用 0.28mm 层高 + 15% 填充快速验证；终版 0.16mm + 30%。打印后务必用 Ø3.2/Ø4.3 钻头、Ø6.3 铰刀过一遍运动副孔。

## 4. 装配顺序（照抄即可）

1. 修孔、去毛刺
2. **电子先在桌面裸接跑通**（别装进壳）
3. 摇杆拧进底座口袋（4×M2）；主控拧在底座 4 个 PCB 柱上
4. 开关压进开关架 → 焊线（每个开关一根信号线 + 公共 GND）→ 开关架拧在底座上 → 扣键帽
5. 合盖铰链：凸耳交错 → 插 M4 螺杆 → 两侧尼龙垫圈 → 螺母拧到"有阻尼不卡"
6. 托盘：轴颈插进导轨轴承孔 → M3 螺钉 + 尼龙垫圈 + 方螺母 → 调到"手拨能转、松手不掉"
7. 合盖、反复换形态 20 次，看有无松动

## 5. 升级待办（以后再说，不阻塞原型）

| 优先级 | 事项 | 说明 |
|---|---|---|
| P1 | 电池 + 充电板内置 | 拔掉 USB 线独立玩 |
| P1 | 加固手机固定 | 倒甩/装兜会滑出来时再加：MagSafe 环压进托盘 + 合盖磁铁 ×8（托盘轴颈旁留屏蔽，避免霍尔漂移），或打印 TPU 卡爪 |
| P1 | 有线低延迟（可选） | 走相机转接头，或拆一个 MFi 手柄取板（真·Lightning 直插）。需要改结构：deck 前端加"短线舱 + 拔插位" |
| P2 | 肩键杠杆 + 后壁开关 | 手感更完整 |
| P2 | 完整 PCB | 板框已生成（`out/pcb/`），要干净/批量时打板 |
| P2 | 硬限位（坡形挡块） | 防止暴力过转，现在只靠凸点+摩擦自锁 |
| P3 | 相机通孔（合盖也能拍照） | 需要托盘轴偏心，结构复杂一档 |
| P3 | 磁吸可拆 deck（瘦身版） | 合盖厚度从 44mm 降到 ~20mm 的唯一办法 |
| P3 | 竖屏 GB 布局变体 | 现在是横屏 3DS 布局，换布局要改 deck + 托盘 |
| P3 | 换机型（Max/Plus 那档） | 手机宽 >157mm 时托盘要放大，会连锁放大盖框和底座 |
| P3 | 固件打磨（摇杆曲线/中心漂移补偿/连发/OTA/多设备切换） | 基础固件已写完，这些都属锦上添花，单项 0.5–4 小时（详见 `firmware/README.md`） |

## 6. 关键决策记录（为什么这么做）

| 决策 | 原因 |
|---|---|
| 两根**平行**轴（θ 合盖 + φ 托盘翻转），轴都沿 X | YZ 平面内是简单连杆：不用万向节、**转轴里一根线都不走** → 可 3D 打印 |
| 托盘轴放在**托盘板中面** | 翻转 180° 后托盘仍占同一层，只有手机从盖内侧换到盖外侧；否则要么盖变厚、要么撞底座 |
| 铰链凸耳**全部移到左右两侧** | 托盘翻转的扫掠圆（半径 37.9mm）内不能有任何盖的材料，中间不能有腹板 |
| 控制井下沉 + 摇杆再沉进口袋 | 合盖时手机屏幕平面就是底座顶面，所有控制件必须低于它（现在净空 3.5mm） |
| 按键簇前移 3mm（y −14 → −17） | 否则 ABXY 上排/十字上臂的开关焊盘会压进 Ø32 摇杆口袋（那里没有板子/开关架可放） |
| 不做 PCB，用打印开关架 | 原型阶段最快：摇杆直接拧底座、主控用现成开发板、11 个开关由打印件定位 |
| 蓝牙而不是有线 | 托盘要转 180°，有线必须过线/拔线；Lightning 有线还要相机转接头或拆 MFi 手柄 |
| 底盘/盖框与机型无关 | 只有托盘（160×74.5×7 接口标准）随手机变；上限 157×71.5mm，Max/Plus 要整体放大 |

## 7. 变更记录

| 日期 | 做了什么 |
|---|---|
| 2026-09-14 | **验证链进了 CI**：新增 `verify` workflow —— 每次 push/PR 自动跑「姿态干涉检查（内含尺寸断言）→ viewer 矩阵 vs poses.pose → 自动取景 → 运行期冒烟（抓黑屏类异常）」，再加一个 docs 新鲜度检查（重跑 `make_docs.py` 后 git diff 必须为空）。顺带修掉两处漂移：`leaderboard` workflow 现在也刷新 `web/leaderboard.json` 并跑 `make_docs.py`，`docs/LEADERBOARD.md` / `docs/leaderboard.json` 不会再落后 |
| 2026-09-14 | **模块化底座：新增键盘底座（vibecoding 用）**。铰链接口升级为模块标准（销孔/凸耳/贴合面 19mm/磁铁/密封槽固定），换底座只需拔插 M4 销。新件 deck_keyboard（160cm³/~71g/6–8h）：把控制井换成迷你蓝牙键盘模块（150×60×7.5，买现成、自带 BLE 与电池）的舱位，键面比边缘低 0.5mm，前缘 0.8mm 挡边，侧壁 14×6 充电口；手机在上盖当屏幕 = 迷你笔记本。验证：新增键盘底座/模块的配对检查（0 接触属正常），4 项全过；演示页加底座切换并纳入冒烟测试 |
| 2026-09-14 | **托盘加围边（手机嵌进托盘）**：托盘加一圈 7.4mm 高围边（比屏幕高 0.7mm）+ ±X 两端取手机缺口。φ=0 围边朝内（悬在控制井上方，离最高键帽 3.5mm）、φ=180 朝外 → **两个方向手机都嵌在托盘里，不再有"贴在框背面的板砖"感**，总厚度不变。围边下半段外轮廓内缩以控制扫掠半径（37.85 vs 横梁 39，余量 1.15mm）。修掉两处：`wall_in` 未贯穿导致围边下半段成实心板（131→64.8cm³）、缺口内侧 0.05mm 亚体素薄片（非流形边） |
| 2026-09-14 | **游戏凑满五款 + 排行榜上屏**：新增**贪吃蛇**（十字键）与 **Flappy**（单键 A）；屏幕下拉框新增「🏆 排行榜（实时）」——把 `leaderboard.json` 直接画在 3D 手机屏幕上（五列 Top8）；本地最高分扩展到五款 |
| 2026-09-14 | **排行榜上线（零后端）**：演示页玩完点「提交成绩」→ 自动开一个预填好的 GitHub Issue（`score` 标签）→ `leaderboard` workflow 汇总各游戏 Top10 → 写进 README 标记区 + `docs/leaderboard.json`。用测试 issue 走通全流程（**13 秒出榜、删除后 10 秒清空**）|
| 2026-09-14 | **打砖块手感修复**：出射角改成只由"击球点偏离挡板中心"决定（0°~±58°），之前沿用来球的垂直分量 → 越打越平、总往一侧横飘；小球改为分步推进（不再高速穿透挡板）；补回被误删的"掉球扣命"。赛车删除，改上**俄罗斯方块 + 打砖块**（分别展示十字键与模拟摇杆），启动视角改为对准屏幕中心 |
| 2026-09-14 | **减薄 + 精致化**：底座 20→19mm、盖 16→15.1mm、托盘板 7→6.6mm、铰链凸耳 Ø16.4→Ø14 且轴心后移（尾部伸出少 4mm）、托盘轴颈 Ø16→Ø14.8；合盖手机模式 44.3→**42.4mm**，新增"**日常模式**"（拧下 M4 螺杆取走底座 = **22.5mm** 厚保护壳）。改完重跑全部验证：9 件仍全水密、13 项姿态仍无干涉 |
| 2026-09-14 | 3D 演示页：屏幕黑边 4→3mm 且圆角与手机同心、**修正屏幕左右镜像**（之前从正面看画面是反的，导致人物移动和按键相反）、默认视角改成正面 3/4 且拉近（开机即能玩的视角）、新增**伪 3D 赛车游戏**、新增"日常模式"按钮；机构常数改由 `web/params.json` 注入 |
| 2026-09-14 | **发布到 GitHub + Pages**：<https://github.com/Li-Mingshuang/flipdeck>（main / docs），演示页 <https://li-mingshuang.github.io/flipdeck/>；新增 `ORDER_KIT.md`（代打话术+首件检查单）、`make_docs.py`、`LICENSE`（代码 MIT / 硬件 CC BY 4.0）、`.gitignore`；README 改成项目门面 |
| 2026-09-14 | 3D 演示页大升级：修屏幕方向（原来躺倒 90°）、**键盘可玩的小游戏**（移动/跳跃/金币/史莱姆/关卡）、键帽按下动画 + 十字键跷跷板 + 摇杆摆动（键盘 & 鼠标直接拖摇杆帽）、CRT 扫描线滤镜、自定义图片贴屏；`web_export.py` 拆成 17 个可独立动画的小件 |
| 2026-09-14 | **固件写完**：`firmware/flipdeck_gamepad/flipdeck_gamepad.ino`（BLE HID + 摇杆自动标定/死区/滤波 + 十字键帽子开关 + 电量可选）+ `firmware/README.md`（装环境/烧录/配对/标定/排错）。路线定为**自建**（ESP32-S3，不用拆供体） |
| 2026-09-14 | 澄清手机固定（挡墙+沉台就够，不用胶不用磁铁）与连接方式（蓝牙/有线成本对比：拆蓝牙手柄取板最省，¥60–100 且不用写固件）；采购清单改成"供体手柄优先" |
| 2026-09-14 | 建活文档 + `status.py`；确定"原型优先"路线；原型简化项与升级待办分离 |
| 2026-09-14 | 出打印开关架 `switch_frame.stl`（替代 PCB）；按键簇前移 3mm 修掉与摇杆口袋的冲突；键帽改成嵌进孔内压 2mm 开关；PCB 板框 + 自检 9 项全过 |
| 2026-09-14 | 电子方案文档 `ELECTRONICS.md`（采购/引脚表/固件/Lightning 有线三条路）；`DIY_GUIDE.md` 分期计划 |
| 2026-09-14 | 切换到 iPhone 12；一壳多机边界算清（可装上限 157.0×71.5mm） |
| 2026-09-14 | 间隙检查公式修正（`min max(dA,dB)`）、托盘位姿修正（绕轴心旋转）、密封条槽同心内缩、体素相位自动搜索 → 9 件全水密、13 项姿态检查全过 |
| 2026-09-14 | 机构定型：双平行轴 + 托盘中面轴 + 铰链走两侧；STL/渲染/报告流水线（`build.py`） |

## 8. 文档地图

| 文件 | 内容 |
|---|---|
| `PROGRESS.md` | **本文：进度 + 计划 + 决策 + 待办** |
| `README.md` | 项目门面：原理、验证数据、快速开始、仓库结构、许可 |
| `ORDER_KIT.md` | **给代打的话（可直接复制）+ 0 期首件检查单 + 1 期机构验证清单** |
| `DIY_GUIDE.md` | 打印方案、装配顺序、分期计划、风险清单、一壳多机边界 |
| `ELECTRONICS.md` | 采购清单、Lightning 有线三条路、打印开关架用法、引脚表、固件、动手顺序 |
| `firmware/README.md` | 固件：装环境、烧录、配 iPhone、摇杆标定、排错、接线对照 |
| `out/BUILD_NOTES.md` | 最近一次构建：零件网格数据 + 间隙检查结论 |
| `out/clearance_report.md` | 13 项姿态间隙明细 |
| `out/pcb/` | PCB 板框（DXF/SVG/PNG）+ 板级自检报告 |
| `out/ip12/` | iPhone 12 版渲染图（含 total 拼图 contact_sheet_ip12.png） |
| `web/` + `docs/` | 交互式 3D 演示（`docs/` = Pages 发布产物，由 `make_docs.py` 生成） |
| `LICENSE` | 代码 MIT / 硬件 CC BY 4.0 |

## 9. 发布与更新（GitHub）

- 仓库：<https://github.com/Li-Mingshuang/flipdeck>（公开，默认分支 `main`）
- 在线演示：<https://li-mingshuang.github.io/flipdeck/>（Pages 源 = `main` 分支 `/docs`）
- 更新流程：改完东西后

```powershell
python build.py --render-dir ip12     # 重出 STL + 渲染 + 报告
python web_export.py                  # 重出网页用轻量 STL
python make_docs.py                   # 同步到 docs/（Pages）
python status.py                      # 刷新本文状态块
git add -A; git commit -m "..."; git push
```

- 许可：代码 MIT / 硬件设计（STL、Pages）CC BY 4.0

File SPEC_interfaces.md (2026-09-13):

# flipdeck-cad 接口规范（内部约定，勿改）

## 环境事实
- Windows。Python 解释器：`C:\Softwares\miniconda3\python.exe`（3.12.9）
- **可用依赖只有 `numpy` 和 `PIL`（Pillow）**。没有 scipy / trimesh / manifold3d / matplotlib / cadquery / OpenSCAD / FreeCAD。
- **没有网络**：`pip install` 会超时，绝对不要尝试安装任何包。
- 运行脚本用 pwsh，例如：`& "C:\Softwares\miniconda3\python.exe" "C:\myFiles\codes\deepseek\flipdeck-cad\flipdeck\meshlib.py"`
- 文件沙箱是 workspace-write：只能写 `C:\myFiles\codes\deepseek\` 下的文件。
- 工作目录：`C:\myFiles\codes\deepseek\flipdeck-cad\`

## 通用几何约定
- 单位 **毫米**，浮点。
- 右手坐标系，**Z 轴朝上**。
- 网格 = `(verts, tris)`：`verts` 是 `np.ndarray` shape `(N,3)` float64；`tris` 是 `np.ndarray` shape `(M,3)` int32，索引 `verts`，**三角形顶点从外部看是逆时针（外法线朝外）**。
- 每个网格必须是**闭合、水密、流形**（每条边恰好被 2 个三角形共享），不能有孤立顶点或退化三角形。

## SDF 约定（两个文件都要遵守）
一个 SDF 是 `f(p: np.ndarray[(...,3)]) -> np.ndarray[...]`，返回有符号距离：
- `f < 0` 在实体内部，`f > 0` 在外部，单位毫米。
- 必须支持任意形状的 broadcast 输入网格，即内部所有运算都用 numpy 向量化（不要写 python 逐点循环）。
- 不要求严格精确的欧氏距离，但**零等值面必须准确**（这是切出来的面）。

## 文件 A：`flipdeck/meshlib.py`（负责人 A）
只创建/修改这一个文件，不要碰别的文件。

```python
def sample_grid(sdf, lo, hi, voxel):
    """在 p = lo + (i,j,k)*voxel 的规则网格上求 sdf。
    lo/hi: (3,) 世界坐标 mm；voxel: float mm。
    返回 (F, axes) 。"""
    # F: np.ndarray shape (nx,ny,nz) float32/float64 = sdf(p) 在网格点的值
    # 网格点数满足 nx = int(ceil((hi[0]-lo[0])/voxel)) + 1，其余轴同理
    # axes: (xs, ys, zs) 一维坐标数组，长度分别 nx, ny, nz

def surface_nets(sdf, lo, hi, voxel):
    """SDF -> 闭合三角网格（Surface Nets / Naive Dual Contouring 风格）。
    返回 (verts, tris)：verts (N,3) float64，tris (M,3) int32，满足上面"通用几何约定"。
    - 每个跨越零等值面的体素单元最多产生 1 个顶点（顶点取该单元内 12 条棱上交点的平均）。
    - 四边形的生成与绕向必须保证外法线朝外。
    - 必须闭合：不允许边界处出现开放边（在 lo/hi 周围留出足够 padding，使零等值面
      完全落在采样区域内；如果零等值面碰到采样边界，可以抛 ValueError 提示扩大 bounds）。"""

def write_stl(path, verts, tris):
    """写二进制 STL（80 字节头 + uint32 三角形数 + 每个三角形 50 字节）。返回 path。"""

def read_stl(path):
    """读回二进制 STL，返回 (verts, tris)。仅用于自测/验证。"""

def mesh_stats(verts, tris):
    """返回 dict，至少包含：
    n_tris(int), n_verts(int), volume(float, 由散度定理算出的闭合体积 mm^3),
    watertight(bool), bbox(tuple((6,) 的 min/max)),
    boundary_edges(int, 只被 1 个三角形共享的边数),
    nonmanifold_edges(int, 被 >2 个三角形共享的边数)"""

def voxel_occupancy(sdf, lo, hi, voxel):
    """返回 (occ, axes)，occ = (F < 0) 的布尔体素（在体素中心求值）。供干涉检查用。"""
```

自测要求（写在文件末尾 `if __name__ == "__main__":`，必须真的跑一遍并把结果打印出来）：
1. 球：`sdf = |p| - 20`，bounds `[-25,-25,-25]..[25,25,25]`，voxel 0.5：`mesh_stats` 的
   - `watertight is True`，`boundary_edges == 0`，`nonmanifold_edges == 0`
   - 体积误差 < 2%（真值 4/3·π·20³ ≈ 33510）
   - bbox 每个方向与 ±20 的偏差 < 1 个 voxel
2. 立方体 `max(|x|-15,|y|-10,|z|-5)`，voxel 0.5：体积误差 < 3%（真值 30·20·10=6000），水密。
3. 一个带 Ø4 通孔的方块（`union(box, -cylinder(r=2))`，用最朴素写法即可）：水密，且孔在 STL 里确实存在（可在孔轴线上采样网格点做点-内部判定，或用 `voxel_occupancy` 检查轴心处为空）。
4. 性能：一个 170×90×25 mm 的盒子，voxel 0.4，`surface_nets` 在 60 秒内完成，且内存不炸。

交付时在最终回复里给出：文件路径、每个自测的实测数字（体积误差、水密性、耗时）、以及任何未达标项。

## 文件 B：`flipdeck/render.py`（负责人 B）
只创建/修改这一个文件，不要碰别的文件。

```python
def render(parts, path, size=(1000, 760), azimuth=35.0, elevation=22.0,
           target=(0.0, 0.0, 0.0), distance=None, ortho_scale=None,
           bg=(0.09, 0.10, 0.12), ssaa=2, shadows=False):
    """纯 numpy + PIL 的软件渲染器（正交投影 + z-buffer + 平面着色）。
    parts: list[dict]，每个 dict:
        {"verts": (N,3) float64, "tris": (M,3) int32, "color": (r,g,b) 0..1}
        可选 "alpha": float（默认 1.0，用于手机/被遮挡件半透明预览）
    path: 输出 PNG 路径，返回 path。
    相机：绕 target 的球坐标 —— azimuth 度（绕 Z 轴），elevation 度（相对 XY 平面）。
    distance 为 None 时自动取所有点包围球半径 * 3；ortho_scale 为 None 时自动取
    包围球直径 * 1.15。size 是最终 PNG 尺寸，ssaa 是超采样倍数（内部按
    size*ssaa 渲染再降采样）。
    要求：
    - 平面着色：面法线 · 光照方向，光照方向来自相机方向略偏上（headlight）+
      环境光 + 一点侧向补光，让相邻面能看出层次；不要出现全黑或全白。
    - z-buffer 正确（近处遮挡远处），不透明件之间不能互相穿帮。
    - 用 PIL 做降采样（Image.resize 用 LANCZOS）和 PNG 保存。
    - 无输入三角形时也要能正常输出一张背景色 PNG。"""
```

自测要求（同样写在 `if __name__ == "__main__":`，必须跑并把结果打印/落盘）：
1. 渲染一个立方体 + 一个球 + 一个圆柱（三个不同颜色，位置错开），存到 `out/selftest_render.png`（1000×760），要求：
   - 文件存在、尺寸正确
   - 图像不是纯背景色（统计非背景像素占比 > 3%）
   - 三个物体在图像上互不重叠且都可见（可用连通域或颜色计数粗略验证：每种颜色像素数 > 500）
2. 渲染性能：把上面的场景复制成约 150k 三角形（可网格细分或平铺），要求 1000×760、ssaa=2 下 60 秒内完成，并打印耗时。
3. 验证 z-buffer：球放在立方体前面时，球的像素不被立方体覆盖（颜色计数验证）。

交付时在最终回复里给出：文件路径、自测数字（非背景像素占比、各颜色像素数、耗时）、以及任何未达标项。

## 禁止事项
- 不要 pip install，不要联网，不要用 OpenSCAD/FreeCAD（不存在）。
- 不要修改 `SPEC_interfaces.md`、`params.py`、`sdf.py`、`parts.py`、`poses.py`、`build.py`（这些由别人负责）。
- 不要读/改 `out/` 里除自己自测产物以外的文件。

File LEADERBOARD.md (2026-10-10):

# 🏆 flipdeck 排行榜（各游戏 Top 10）

> 成绩通过 **GitHub Issue** 提交，由 **GitHub Actions 自动汇总** —— 有人提交就会自动更新这份榜单和 README。
> 提交方式：在 [演示页](https://li-mingshuang.github.io/flipdeck/) 玩完点「提交成绩」，或者手动开一个标题带 `[SCORE]` 的 issue。
> 同一玩家每款游戏只记最好成绩；分数靠自觉，这是个友好排行榜。

## 🎮 跑酷（`run`）

_还没有成绩 —— 来占个第一？_

## 🎮 俄罗斯方块（`tetris`）

_还没有成绩 —— 来占个第一？_

## 🎮 打砖块（`break`）

_还没有成绩 —— 来占个第一？_

## 🎮 贪吃蛇（`snake`）

_还没有成绩 —— 来占个第一？_

## 🎮 Flappy（`flappy`）

_还没有成绩 —— 来占个第一？_

_最后更新：2026-10-10 09:51（UTC）_

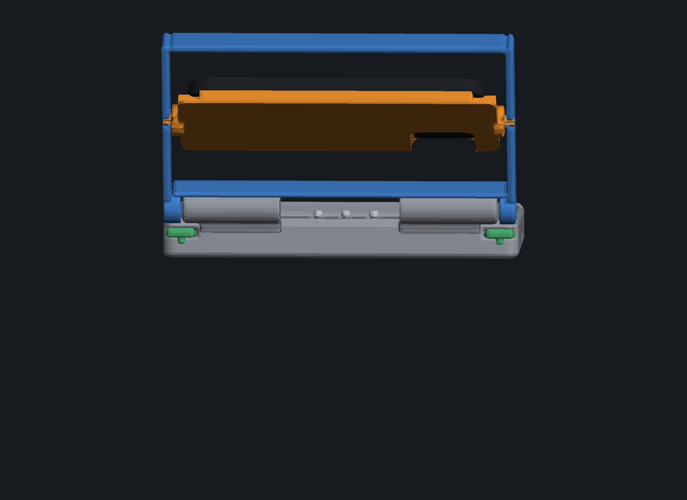
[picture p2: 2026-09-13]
out/render_switch_mid_side.png

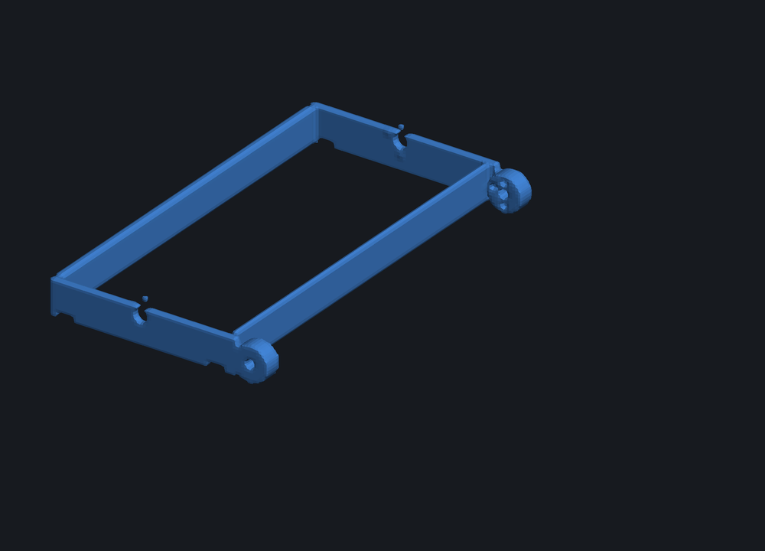
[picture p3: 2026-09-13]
out/part_lid.png

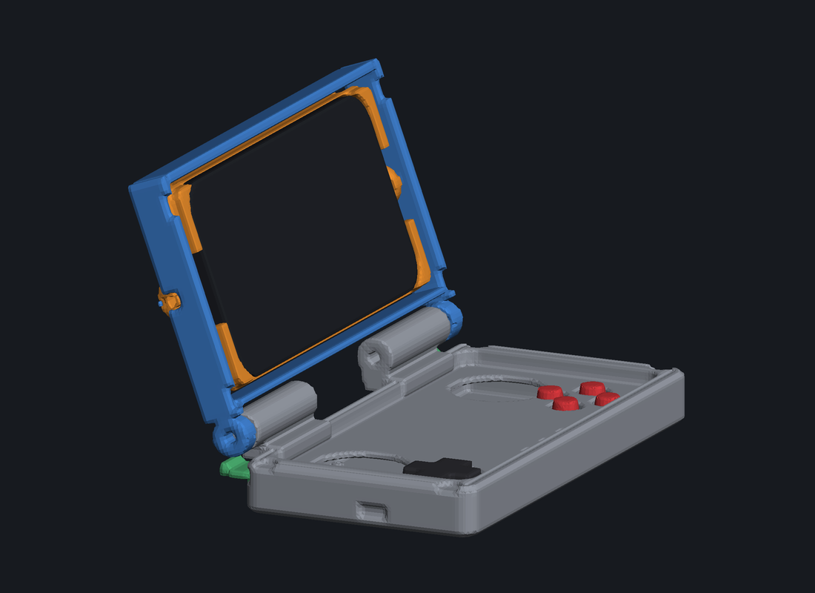
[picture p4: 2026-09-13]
out/ip12/render_open_game_back.png

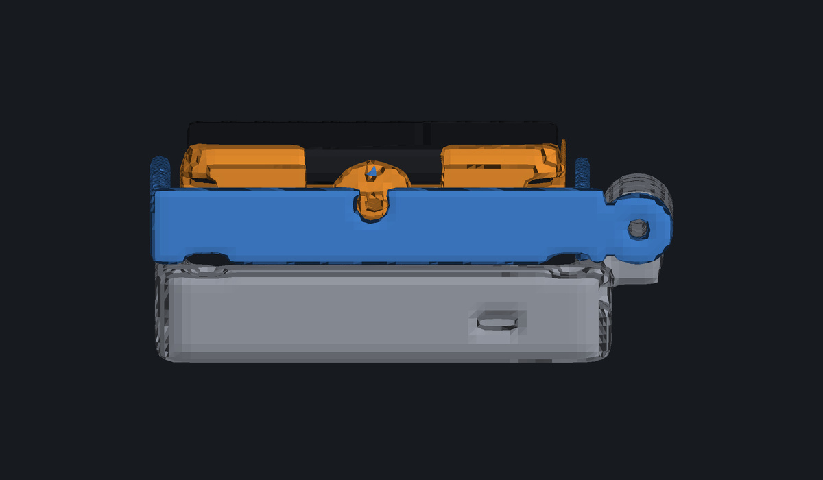
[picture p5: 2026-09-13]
out/ip12/render_section_phone.png

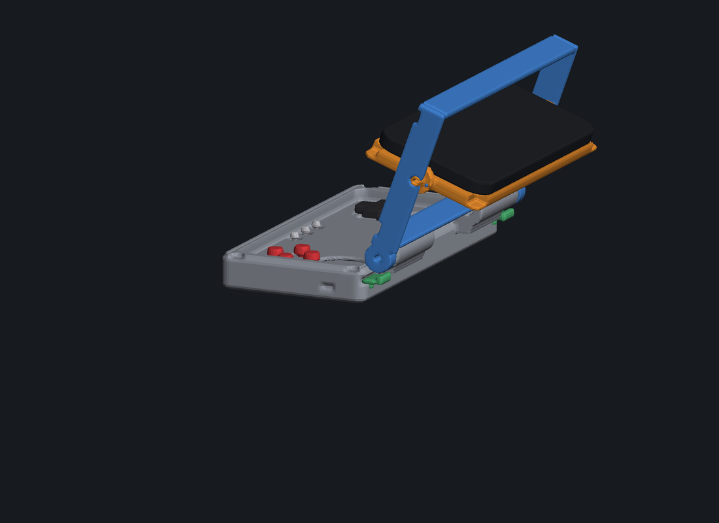
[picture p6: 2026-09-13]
out/render_switch_mid.png

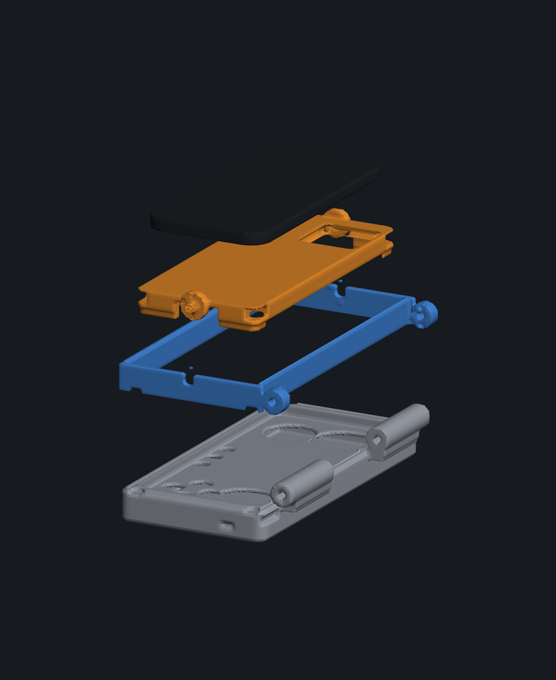
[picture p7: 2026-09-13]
out/ip12/render_exploded.png

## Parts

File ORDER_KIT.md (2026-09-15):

# 下单 / 首件检查单（可直接复制给代打）

> 用途：① 淘宝/嘉立创代打时，把 §1 整段复制给客服；② 收到首件后照着 §3 逐条量。
> 机型：iPhone 12（托盘只对这一款；底座和盖框与机型无关）

---

## 1. 给代打的话（整段复制）

```
你好，打 3D 打印件，FDM 工艺，材料要 PETG（不要 PLA）。文件我发 STL。

【材料与工艺】
1. 材料：PETG（或 ABS/ASA 也可以，但不要 PLA）
2. 层高 0.16mm，壁厚 3 圈，填充 25~30%
3. 不要做整体缩放/尺寸补偿，按 STL 原始尺寸打

【摆放与支撑】
4. deck（底座）：控制井朝上平放；铰链凸耳下方需要支撑
5. lid（盖框）：平放；两侧铰链凸耳下方需要支撑
6. cradle（托盘）：外侧面朝下（手机沉台朝上）；两侧轴颈圆底需要支撑
7. 键帽、肩键杠杆：平放，不用支撑

【精度】
8. 以下孔位请按原尺寸打，不要自动修模改尺寸：
   - 铰链销孔 Ø4.2（deck 和 lid 的凸耳）
   - 托盘轴轴承孔 Ø6.3（lid 两侧导轨）
   - 托盘轴孔 Ø3.2 和螺母坑（cradle）
   - 摇杆模块固定孔 Ø1.9 × 3 深（4 个/侧，分布圆 Ø28）
   - 安装柱螺纹底孔 Ø1.9（deck 内腔 4 个）
9. 运动副（轴颈、销孔、轴承孔）麻烦支撑清理干净，不要留瘤

【数量】每个文件 1 件（lid / cradle / cap_dpad / caps_abxy / caps_small /
        lever_l / lever_r / switch_frame 各 1，共 8 件）；hinge_pin 不用打，我用 M4 螺杆。
        底座二选一：deck.stl（摇杆+按键）或 deck_keyboard.stl（迷你键盘舱），不用都打。
```

**首件只要 1 件**：先只打 `cradle.stl`（约 29g、3–4 小时、估计 ¥30–60），验证没问题再打其它。

## 2. 打印量与预估

| 件 | STL | 体积 | 估算耗材 | 打印时间 |
|---|---|---|---|---|
| deck 底座 | `out/stl/deck.stl` (31.1MB) | 120.5 cm³ | ~54 g | 7–10 h |
| lid 盖框 | `out/stl/lid.stl` (8.1MB) | 29.3 cm³ | ~13 g | 2–3 h |
| cradle 托盘 | `out/stl/cradle.stl` (11.1MB) | 64.8 cm³ | ~29 g | 3–4 h |
| deck_keyboard 键盘底座（可选，和 deck 二选一） | `out/stl/deck_keyboard.stl` (31.8MB) | 160.0 cm³ | ~71 g | 6–8 h |
| switch_frame 开关架 | `out/stl/switch_frame.stl` (9.0MB) | 18.5 cm³ | ~21 g | 2–3 h |
| 键帽 3 件 | `caps_abxy` / `cap_dpad` / `caps_small` | 4.2 cm³ | ~5 g | <1 h |
| 肩键 2 件 | `lever_l` / `lever_r` | 1.4 cm³ | ~2 g | <1 h |
| **合计（游戏版）** | 上面除 deck_keyboard | | **~100–115 g** | **14–18 h** |
| **合计（键盘版）** | deck_keyboard 换掉 deck | | **~118–130 g** | **13–19 h** |

首件（只 cradle）：~29 g / 3–4 h。

**模块化说明**：铰链接口是统一的"模块标准"（销孔 / 凸耳位置 / 贴合面 z=19 / 磁铁 / 密封槽），所以 `deck`（摇杆+按键）和 `deck_keyboard`（迷你蓝牙键盘舱）可以互换，换底座只要拧下 2 根 M4 螺杆抽出来。**不用两个都打**，先打游戏版就行；想 vibecoding 再打键盘版。

整机厚度（本版已减薄）：合盖游戏 **34.1mm**、合盖手机模式 **42.4mm**、**拔掉底座当日常壳 22.5mm**（拧下 M4 螺杆、取下 deck，只剩盖框 + 托盘 + 手机）。

## 3. 0 期首件检查单（收到托盘当天照着量）

准备：托盘 1 件、你的 iPhone 12、卡尺或钢尺、Ø2.0/Ø3.2 钻头、M3×16 螺钉 + M3 方螺母 + Ø10×0.8 尼龙垫圈。

| # | 检查项 | 标准 | 实测 | 结果 |
|---|---|---|---|---|
| 1 | 去支撑、去毛刺 | 沉台和挡墙无瘤、无翘边 | | ☐ |
| 2 | 手机放入沉台（屏幕朝上） | 能自然落进去，四边单边间隙约 0.35mm | | ☐ |
| 3 | 挡墙高度 | 高出手机背面约 1.3mm（手指轻推手机不滑出） | | ☐ |
| 4 | 相机凸台落位 | 后摄凸起落进让位坑，手机背面能贴平（不翘） | | ☐ |
| 5 | MagSafe 环坑（可选） | Ø56/Ø44 环能压进去（不装磁铁可跳过） | | ☐ |
| 6 | 挡墙不遮屏幕 | 正视屏幕四边，挡墙不压到显示区 | | ☐ |
| 7 | 两侧轴颈孔 | Ø3.2 钻头能顺畅穿过（偏小就用钻头过一遍） | | ☐ |
| 8 | 轴颈外形 | Ø6.0 左右，圆面无瘤；两侧对称 | | ☐ |
| 9 | 螺母坑 | M3 方螺母能放进轴颈内侧坑（深 2.2） | | ☐ |
| 10 | 平面度 | 托盘板面放在桌上不晃（不翘曲） | | ☐ |
| 11 | 零件尺寸 | 长 160 ± 0.5、宽 74.5 ± 0.5（用卡尺量外廓） | | ☐ |

**判定**：
- 1–10 全过 → 继续打 1 期（lid + deck + hinge_pin，0.28mm 层高快速验证版）
- 第 4 项不过（相机坑位置不对）→ 量出你的相机凸台中心距手机中心的位置告诉我，我改 `params.PHONES['ip12'].cam_x/cam_y` 重出托盘
- 第 2/3 项不过（太紧/太松）→ 告诉我实测间隙，我改 `PHONE_FIT`（现在 0.35mm）
- 第 7 项不过（孔偏小）→ 钻头过一遍即可，不用重打

## 4. 1 期装起来之后要看的（机构验证）

| # | 检查项 | 标准 |
|---|---|---|
| 1 | 托盘轴颈插进盖框导轨轴承孔 | 能转，不卡死、不晃 |
| 2 | M3 螺钉 + 尼龙垫圈 + 方螺母锁紧 | 手拨能转、松手不掉 |
| 3 | 0° / 110° / 180° 三个定位 | 有"咔"感（棘轮凸点咬进凹坑） |
| 4 | 合盖铰链（M4 螺杆） | 阻尼合适，能停在 110° |
| 5 | 合盖（游戏位） | 手机屏幕离控制面还有 2–3mm，不顶键帽/摇杆（可用纸片垫高模拟） |
| 6 | 翻转托盘 | 开盖状态下能拨 180°，全程不刮盖框 |
| 7 | 合盖（手机位） | 手机屏幕朝上，能当普通手机用；按键被盖住 |
| 8 | 反复换形态 20 次 | 无松动、无掉磁、无裂 |

有不过的项，把现象和实测尺寸丢回给我，我改参数重出对应零件（只有托盘跟机型相关，deck/lid 不变）。

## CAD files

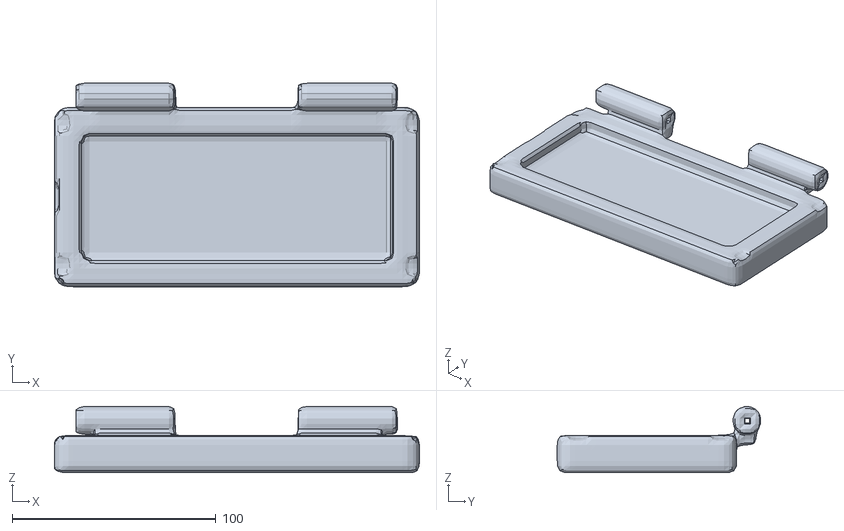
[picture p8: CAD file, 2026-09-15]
docs/stl/deck_keyboard.stl
179.0 x 99.8 x 32.4

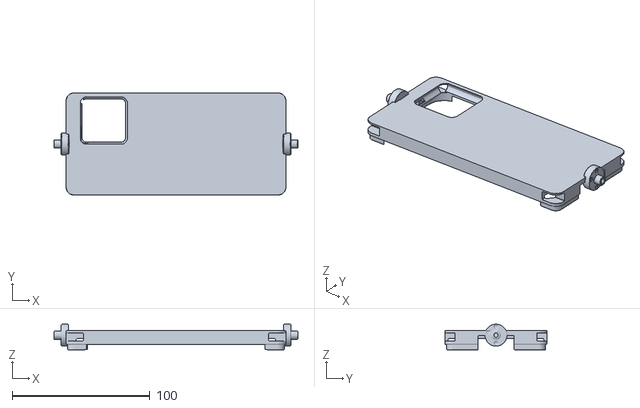
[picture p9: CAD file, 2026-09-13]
out/stl/cradle.stl
177.4 x 74.5 x 18.7

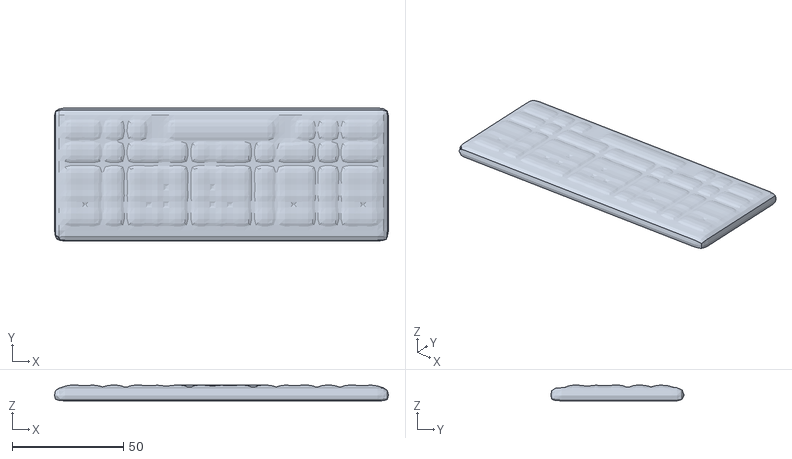
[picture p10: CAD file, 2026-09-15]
docs/stl/keyboard_module.stl
150.0 x 59.9 x 7.05

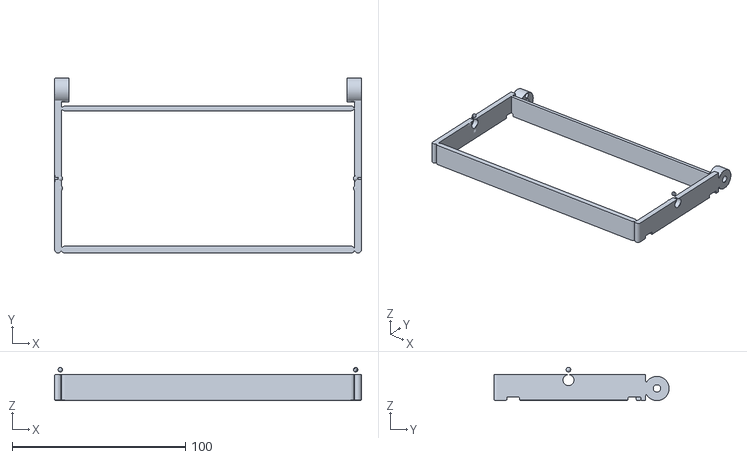
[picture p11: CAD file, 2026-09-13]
out/stl/lid.stl
177.0 x 101.0 x 19.1

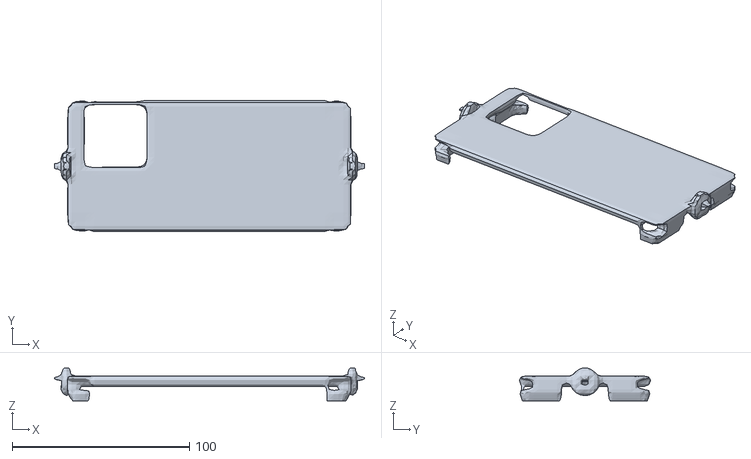
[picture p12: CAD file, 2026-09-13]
docs/stl/cradle.stl
174.8 x 74.1 x 18.6

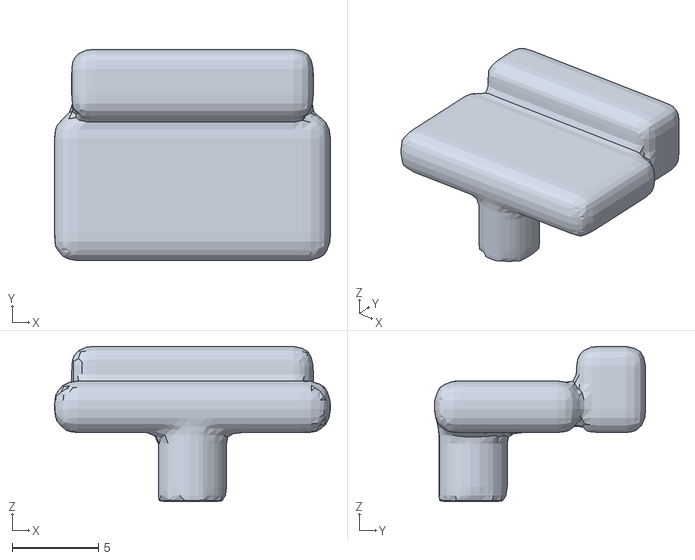
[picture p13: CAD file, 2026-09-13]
out/stl/lever_l.stl
16.0 x 12.2 x 9.00

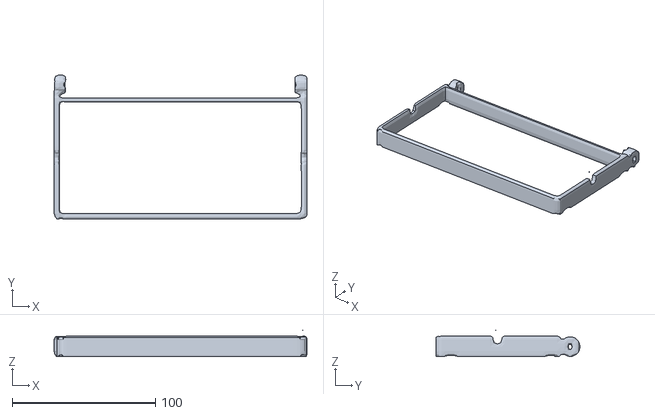
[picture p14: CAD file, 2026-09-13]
docs/stl/lid.stl
176.9 x 100.9 x 18.4

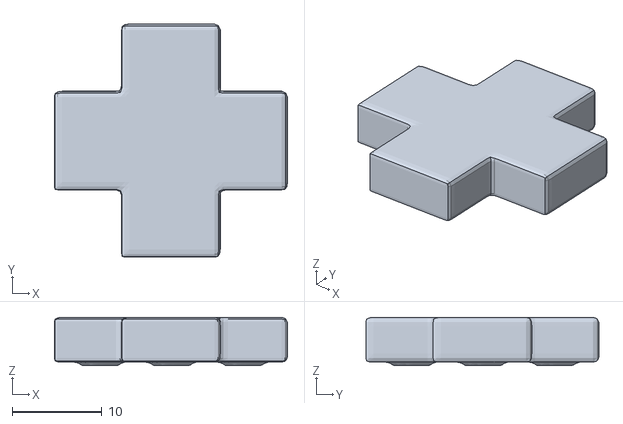
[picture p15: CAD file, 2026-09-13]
out/stl/cap_dpad.stl
26.0 x 26.0 x 5.40

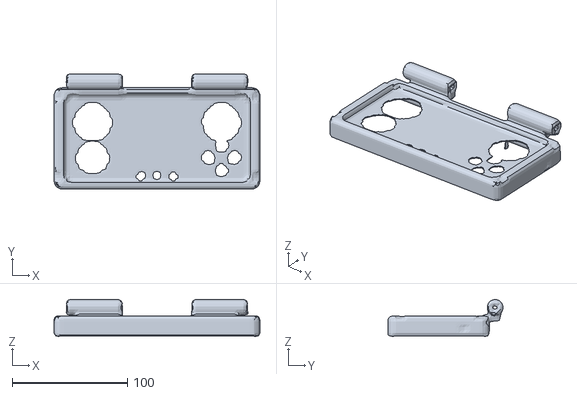
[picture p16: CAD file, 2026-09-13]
web/stl/deck.stl
179.0 x 99.8 x 32.2

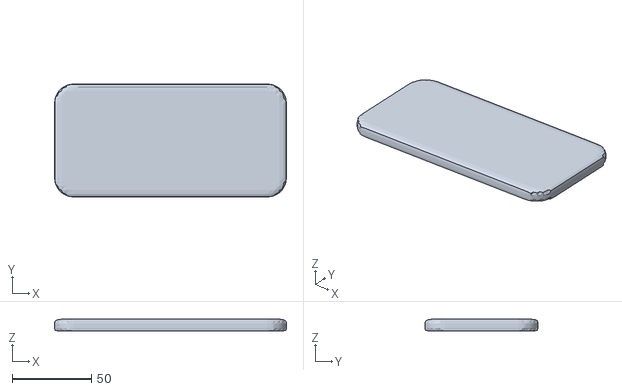
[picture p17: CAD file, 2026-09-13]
docs/stl/phone.stl
146.7 x 71.5 x 7.40

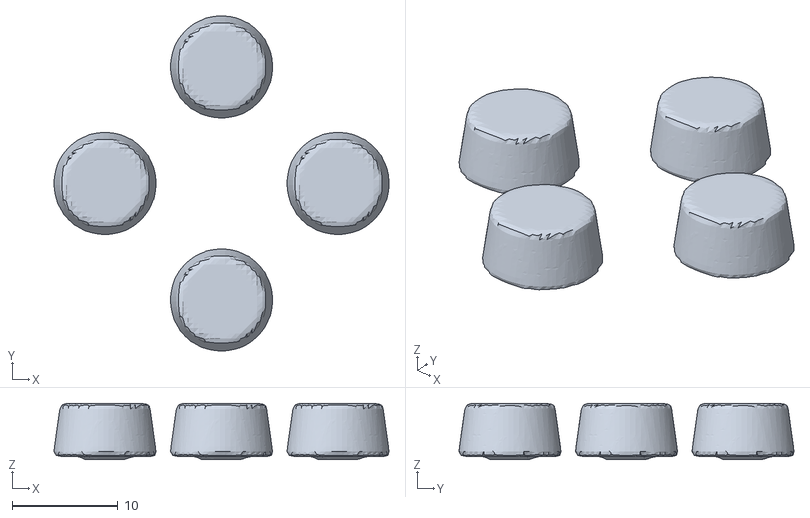
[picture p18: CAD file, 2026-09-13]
out/stl/caps_abxy.stl
31.6 x 31.6 x 5.30

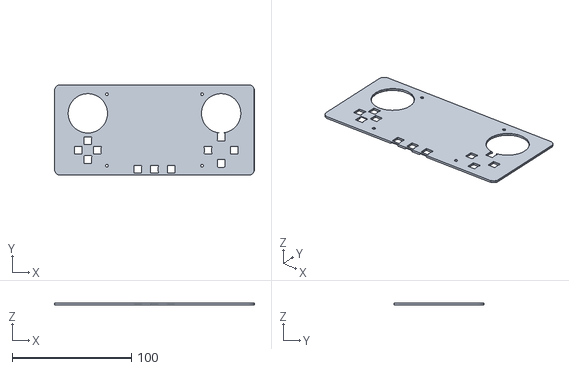
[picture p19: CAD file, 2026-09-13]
out/stl/switch_frame.stl
168.0 x 76.0 x 1.80

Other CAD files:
out/pcb/flipdeck_pcb_outline.dxf
docs/stl/cap_a.stl
docs/stl/cap_b.stl
docs/stl/cap_dpad.stl
docs/stl/cap_home.stl
docs/stl/cap_select.stl
docs/stl/cap_start.stl
docs/stl/cap_x.stl
docs/stl/cap_y.stl
docs/stl/lever_l.stl
docs/stl/lever_r.stl
docs/stl/stick_l_cap.stl
docs/stl/stick_r_cap.stl
docs/stl/sticks_base.stl
out/stl/caps_small.stl
out/stl/lever_r.stl
web/stl/cap_a.stl
web/stl/cap_b.stl
web/stl/cap_dpad.stl
web/stl/cap_home.stl
web/stl/cap_select.stl
web/stl/cap_start.stl
web/stl/cap_x.stl
web/stl/cap_y.stl
web/stl/lever_l.stl
web/stl/lever_r.stl
web/stl/stick_l_cap.stl
web/stl/stick_r_cap.stl
web/stl/sticks_base.stl

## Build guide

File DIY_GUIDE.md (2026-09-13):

# flipdeck DIY 落地方案（打印 + 电子 + 装配）

> 结论先说：**结构可打印、电子件可买、装配是手工能干的活**。难度不在"能不能做出来"，而在四处：
> ① 铰链/棘轮的摩擦调校 ② 托盘磁铁对霍尔摇杆的干扰 ③ 内腔高度预算 ④ 手机固定方式。
> 所以别一次全打——按 §7 的分期走，0 期半天就能验证机构是否成立。
>
> 本方案默认机型：**iPhone 12 / 12 Pro（146.7 × 71.5 × 7.4 mm）**，已写进 `flipdeck/params.py`。

---

## 1. 一壳多机：能装多大，哪种情况要重做外壳

参数表的结论已经算进 `params.sanity()`，每次构建都会打印。核心事实：**代码里 deck 和 lid 的几何完全不引用手机参数**，换手机只有 `cradle`（托盘）要变。

托盘外廓就是"接口标准"：**160 × 74.5 × 7.0 mm**，四周挡墙最少留 1.0mm（挡墙负责定位+托住手机，磁铁只是后期加固，见 §6）。

| 机型 | 机身 | 能否用同一套 deck/lid |
|---|---|---|
| **iPhone 12 / 12 Pro** | 146.7 × 71.5 | ✔ 当前默认（挡墙 X 6.3 / Y 1.15mm） |
| iPhone 15 / 17 / 16 Pro | 147.6~149.6 × 71.5 | ✔ 直接可用 |
| Pixel 8 | 150.5 × 70.8 | ✔ |
| iPhone 12 / 16 **Pro Max** | 160.8~163 × 77.6~78.1 | ✘ 要加宽托盘到 164~166 × 81，**连锁放大 lid 窗口和 deck 宽度** |

**可装上限：157.0 × 71.5 mm**（托盘 160×74.5 − 两侧 0.35 间隙 − 两侧 1.0 挡墙）。
即 6.1"~6.3" 非 Max 机型通用；Max/Plus 那类 78mm 宽的机身必须整体放大（不是"换个卡扣件"能解决的）。

换机型的实际影响：
- 只有 `out/stl/cradle.stl` 会变（渲染里的手机模型也变），**deck.stl / lid.stl 字节级不变**（可用 `python -c "..."` 对比 SDF 值验证，见 §9）。
- 手机厚度会改"合盖手机模式"的总厚：iPhone 12（7.4mm）→ **42.4mm**；16 Pro（8.25mm）→ 43.3mm。
- 相机让位坑的位置是按机型给的（iPhone 12：`cam_x=-52.5, cam_y=17.0`，37×37 凸台）。这个坑只影响"手机能不能贴平"，不影响机构，首件干装时对一下就行。

## 2. 打印方案

总耗材约 **100–115 g PETG**，总时间 **14–18 小时**（0.16mm 层高）。材料别用 PLA 做铰链凸耳（会蠕变、螺母一拧就裂），**PETG / ABS / ASA** 都行。

| 零件 | 朝向 | 支撑 | 层高 / 壁 | 备注 |
|---|---|---|---|---|
| `deck` | 控制井朝上平放 | 铰链凸耳下方（2 处）+ 肩键槽 | 0.16 / 3 圈 | ~58g、8–11h；摇杆口袋是深腔，别用 0.28 层高 |
| `lid` | 平放（导轨在 Z 向） | 两侧铰链凸耳下方 | 0.16 / 4 圈 | ~14g、2–3h；导轨细长，壁加厚到 4 圈 |
| `cradle` | **外侧面朝下**（手机沉台朝上） | 轴颈圆底（小面积） | 0.16 / 3 圈 | ~27g、3–4h；沉台底面平整很重要 |
| `cap_dpad` / `caps_abxy` / `caps_small` | 平放 | 无 | 0.12 / 3 圈 | 想要好看可以树脂打 |
| `lever_l` / `lever_r` | 平放 | 无 | 0.12 / 3 圈 | 用 PETG，肩键杠杆要有韧性 |
| `hinge_pin` | 竖放 | 无 | 0.16 | 可选；**建议直接用 Ø4 不锈钢圆棒/M4 螺杆** |

打印后处理（必做）：
- 用 **Ø4.3 钻头**过铰链销孔、**Ø6.3 铰刀**过托盘轴承孔、**Ø3.2 钻头**过托盘轴孔 —— 体素网格化有 ±0.2mm 级偏差，不过这四类孔会偏小。
- 定位凹坑（Ø2.8×0.7 / Ø3.2×1.3）不用处理，功能不受影响。
- 挡墙、密封条槽（1.5×1.0）在 0.16 层高下都能成型。

## 3. 电子方案（三条路线选一条）

| 路线 | 具体件 | 成本 | 优点 | 缺点 |
|---|---|---|---|---|
| **A（推荐）** | ESP32-S3 模块（WROOM-1 / SuperMini）+ Bluepad32 固件 | ¥40–70 | 生态最好，BLE HID 手柄现成固件，USB-C 也能有线直连 | 功耗比 nRF 高，PCB 稍大 |
| **B** | nRF52840 模块（SuperMini nRF52840 / Feather）+ Adafruit Bluefruit | ¥60–120 | 原生 BLE HID、低功耗、延迟低 | 引脚少，要多焊一点 |
| **C（最省事）** | 拆一个现成蓝牙手柄取其主板（PG-9083s / 8BitDo 等） | ¥50–150 | 不用写固件，按键摇杆都是现成的 | 尺寸不一定合适，按键矩阵要逆向 |

延迟参考：BLE HID 约 10–20ms；USB-C 有线约 2–5ms（代价是占用手机接口，且翻转托盘时线会绕）。**iOS 对 BLE HID 手柄支持良好**（模拟器/原生游戏都能识别）。

**空间预算（已按几何算好）**：
- 内腔：**170 × 79 × 8.5 mm**（净高 8.5mm，PCB+电池+开关都在这层）
- 但两个摇杆口袋（Ø32，位置 `(±56, +14)`）从上面吃掉 7.5mm → **PCB 必须避开这两个圆**：做成"哑铃形"一块板，或两块小板 + 软排线
- 摇杆模块（含帽）总高 **≤ 16mm** 就够（iPhone 12 合盖时手机屏幕在 z=21.4，口袋底 z=5.5）；典型模块 8–13mm，很宽松
- 键帽顶 ≤ 19mm（现在设计在 15.4mm）
- 电池建议 ≤ 88 × 38 × 5.5mm 放中段

**电子清单**：
- 主控 ×1（上表）
- 摇杆 ×2：**优先碳膜电位器摇杆**（避免磁铁干扰）；要霍尔就得先做磁干扰测试（见 §8）
- 轻触开关：6×6×2.5mm ×4（ABXY）、D-pad 用 4×6×6 或十字锅仔片、6×6 ×3（Start/Select/Home）、6×6 ×2（肩键，装在后壁槽里由杠杆压）
- 电池 1500–2000mAh + 保护板；充电用 TP4056/IP5306 + USB-C 母座
- 导线 30AWG 硅胶线、M2 自攻螺丝

## 4. 采购清单（除打印件）

| 类别 | 规格 | 数量 | 用途 |
|---|---|---|---|
| 铰链轴 | M4 螺杆 ~150mm 或 Ø4 不锈钢圆棒 | 1 | 合盖轴 |
| 铰链紧固 | M4 螺母 + Ø10×1.0mm 尼龙垫圈 | 2 + 4 | 摩擦可调 + 凸点定位 |
| 托盘轴 | M3×16 螺钉 + M3 方螺母 + Ø10×0.8mm 尼龙垫圈 | 2 + 2 + 2 | 左右各一组，摩擦可调 |
| 合盖吸合 | Ø8×2mm N35 圆磁铁 | 8 | deck 4 + 盖 4 |
| 手机定位/加固 | 托盘挡墙就够用；MagSafe 磁环（外 Ø56 / 内 Ø44，厚 ~1.6）为**可选加固** | 0–1 | 压进托盘环坑（可点胶）；原型阶段可以不买 |
| 消隙 | 1.5mm 厚 EVA / 泡棉条 | ~1m | 贴 deck 密封条槽 |
| 工具 | Ø3.2 / Ø4.3 钻头、Ø6.3 铰刀、M2 丝锥或自攻 | — | 孔位修整 |

## 5. 装配顺序（照这个走）

1. **修孔**：按 §2 过钻头/铰刀；打印件去毛刺。
2. **先装电子但别封**：PCB、电池、摇杆、按键装进 deck 内腔（摇杆口袋位置是硬约束），USB-C 从左侧壁孔引出。**这一步先不带盖**，直接连手机试：摇杆/按键/肩键全响应、延迟能接受 → 再往下。
3. **合盖铰链**：deck 两个凸耳 + 盖凸耳交错 → 插入 M4 螺杆 → 两侧垫尼龙垫圈 → 拧螺母到"有阻尼但不卡"。检查 0°/110°/180° 三个凹坑能"咔"住。
4. **托盘轴**：托盘轴颈插进两侧导轨的轴承孔 → M3 螺钉从外侧穿入 → 尼龙垫圈 → 拧进轴颈内侧的方螺母 → 调到"手拨能转、松手不掉"，检查 0°/180° 定位凸点能"咔"。
5. **手机固定**：手机直接放进沉台 —— 沉台深 0.8mm、四周挡墙高出手机背面约 1.2mm、单边间隙 0.35mm，正常玩/开盖/翻转/合盖都不会掉（磁铁是可选的后期加固）。确认四角间隙 0.35mm、相机凸台落进让位坑、挡墙不遮屏幕边缘。
6. **合盖**：泡棉条压进 deck 贴合面槽 → 合盖检查吸合、无晃动、键帽不顶手机（设计净空 2mm 以上）。
7. **换形态**：开盖 110° → 拨托盘 180° → 合盖 → 手机屏幕朝上；反复 20 次看有没有松动/掉磁。

## 6. 两个真实设计取舍（先说清楚，免得装完才失望）

- **合盖手机模式相机会被挡**（后摄贴着托盘板）。要合盖拍照得把托盘轴偏心 + 开相机通孔，结构复杂一档，v1 没做。
- **没有硬限位**：0°/110°/180° 靠凸点 + 摩擦自锁，防不住暴力过转。想加"坡形挡块"我可以补（v2 待办里第一项）。

## 7. 分期计划（省钱省时间的顺序）

| 期 | 做什么 | 打印量 | 验证什么 |
|---|---|---|---|
| **0 期** | 只打 `cradle`（~27g，3–4h）＋ 手机 | 最小 | 手机能否贴平、相机坑位置、挡墙托不托得住、干不干涉屏幕圆角 |
| **1 期** | 打 `lid` + `deck` + `hinge_pin`，0.28mm 层高、15% 填充、**不装电子** | ~75g，6–8h | 托盘在导轨孔里能否转、0/110/180 定位手感、合盖是否顺畅、用纸片堆叠模拟控制高度确认不顶手机 |
| **2 期** | 电子件在桌面"飞线裸接"，先用现成手柄/开发板验证 BLE + 延迟 + 手感 | 0 | 固件、按键映射、延迟是否可接受 |
| **3 期** | 打终版（0.16mm）并整机装配 | ~100g，14–18h | 全部 |
| 4 期 | 手感调优：棘轮松紧、摇杆帽高度、肩键行程、泡棉厚度 | 小件 | — |

**0 期和 1 期都通过再打终版**，能省掉一次 15 小时的返工。

## 8. 风险清单（按可能踩坑的顺序）

1. **磁铁 vs 摇杆**：托盘上有 MagSafe 磁环，合盖时距 deck 里的摇杆 15–25mm。霍尔摇杆可能漂移 → **首选碳膜摇杆**；要用霍尔就先实测（把磁环贴到摇杆模块旁边看输出漂移）。
2. **PCB 形状**：必须避开两个 Ø32 摇杆口袋，否则装不进去 → 先量实际摇杆模块尺寸再定板框。
3. **螺母拧太紧顶裂凸耳**：PETG 会蠕变，拧到"有阻尼"就停；不行换 POM 垫圈。
4. **手机固定**：托盘挡墙 + 沉台本身就够（正常使用不会掉）。只有"倒过来甩"或"塞兜里挤"才会滑出来 —— 那时再加 MagSafe 磁环（压进托盘环坑，可点胶）或打印 TPU 卡爪，属于后期加固，不阻塞原型。
5. **体素网格化的公差**：孔径偏差 ±0.2mm 级，务必按 §2 过钻头/铰刀。
6. **换机型**：只能换 `cradle`；机身宽 >157mm（Pro Max / Plus）要整体放大外壳。

## 9. 怎么改机型 / 复现

```powershell
cd C:\myFiles\codes\deepseek\flipdeck-cad
# 1) 改 flipdeck/params.py 里 PHONES 表 + DEFAULT_PHONE
# 2) 重新出件（先看 sanity 打印出的一壳多机适配表）
python debug_slices.py            # 参数自检（含"各机型适配"）
python build.py                   # STL + 渲染 + 一壳多机适配表
```

验证"deck/lid 与机型无关"（换机型前后 SDF 值完全相同）：

```python
python -c "import sys; sys.path.insert(0,'.'); import numpy as np; from flipdeck import parts, params as P; \
a=P.PHONES['ip12']; b=P.PHONES['ip16pro']; \
g=np.stack(np.meshgrid(*[np.linspace(-90,90,40)]*3,indexing='ij'),-1); \
print('deck Δ', abs(parts.build_deck()(g)-parts.build_deck()(g)).max(),
      '| lid Δ', abs(parts.build_lid()(g)-parts.build_lid()(g)).max(),
      '| cradle Δ(应>0)', abs(parts.build_cradle(a)(g)-parts.build_cradle(b)(g)).max())"
```

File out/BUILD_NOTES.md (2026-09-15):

# flipdeck-cad 构建报告

机型：**iPhone 12 / 12 Pro**（146.7 × 71.5 × 7.4 mm）

体素：STL 0.5mm，预览 1.35mm（Surface Nets + 自动采样相位，边角自带约 1 体素圆角）

## 参数自检

- 托盘接口标准 160.0×74.5×6.6（deck/lid 与机型无关）：可装最大 157.3 × 71.8 mm 的手机；当前机型挡墙 X 6.30 / Y 1.15 mm
-   各机型适配：iPhone 12 / 12 Pro ✔；iPhone 12 Pro Max ✘需 PLATE 164×81；iPhone 16 Pro ✔；iPhone 16 Pro Max ✘需 PLATE 166×80；iPhone 15 ✔；iPhone 17 ✔；Pixel 8 ✔
- lid 窗口 169.0 x 78.0；手机 146.7 x 71.5 -> X余量 11.15，Y余量 3.25
- 翻转扫掠半径 托盘 37.85 / 手机 37.12；到前梁 39.00、后梁 39.00 -> 最小余量 1.15mm
- 铰链轴线到托盘轴 51.2mm，凸耳半径 7.0 -> 距扫掠圆余量 6.38mm；凸耳 |x| ∈ (80.0, 88.5) vs 托盘板 |x|<= 80
- deck 后壁顶角到铰链轴线 8.60，凸耳半径 7.0 -> 余量 1.60mm
- 肩键顶端到铰链轴线 11.18 -> 余量 4.18mm
- 合盖游戏位：手机屏幕平面 z=19.0；摇杆帽顶约 z=16.5、键帽顶 z=15.4 -> 净空 2.5mm
- 开关焊盘到摇杆让位圆(Ø33) 最近 +0.50mm @ (56,-6)
- 密封条槽：外壁实体 1.50mm（需 >= 1.0）、槽宽 1.5、深 1.0；槽内缘距控制井 1.40mm
- 整机厚度：合盖游戏 34.1mm；合盖手机模式 42.4mm；展开游戏(θ=110°) 高 114mm × 深 132mm

## 零件（STL 导出）

| 零件 | 三角面 | 实体体积 cm³ | 估算耗材 g | 水密 | 边界面 | 非流形边 | 包围盒 mm | 相位 | 耗时 s | 文件 |
|---|---|---|---|---|---|---|---|---|---|---|
| deck | 653092 | 120.5 | ~54 | ✔ | 0 | 0 | -90..90 × -44..56 × 0..33 | 0.2113 | 48.9 | deck.stl |
| deck_keyboard | 666956 | 160.0 | ~71 | ✔ | 0 | 0 | -90..90 × -44..56 × 0..33 | 0.2113 | 14.3 | deck_keyboard.stl |
| lid | 169784 | 29.3 | ~13 | ✔ | 0 | 0 | -88..89 × -94..7 × -7..12 | 0.8090 | 10.9 | lid.stl |
| cradle | 271008 | 64.8 | ~29 | ✔ | 0 | 0 | -89..89 × -88..-14 × -6..13 | 0.6180 | 7.9 | cradle.stl |
| cap_dpad | 11664 | 2.3 | ~3 | ✔ | 0 | 0 | -69..-43 × -30..-4 × 10..15 | 0.2113 | 1.5 | cap_dpad.stl |
| caps_abxy | 10784 | 1.3 | ~1 | ✔ | 0 | 0 | 40..72 × -33..-1 × 10..15 | 0.2113 | 2.0 | caps_abxy.stl |
| caps_small | 3072 | 0.2 | ~0 | ✔ | 0 | 0 | -17..17 × -36..-30 × 10..14 | 0.2113 | 1.1 | caps_small.stl |
| lever_l | 5452 | 0.7 | ~1 | ✔ | 0 | 0 | -88..-72 × 42..54 × 8..16 | 0.2113 | 0.2 | lever_l.stl |
| lever_r | 5452 | 0.7 | ~1 | ✔ | 0 | 0 | 72..88 × 42..54 × 8..16 | 0.2113 | 0.2 | lever_r.stl |
| switch_frame | 188888 | 18.5 | ~21 | ✔ | 0 | 0 | -84..84 × -38..38 × 8..10 | 0.2113 | 17.3 | switch_frame.stl |

## 装配间隙检查（gap<0 为干涉）

| 场景 | 零件对 | θ | φ | 最小间隙 mm |
|---|---|---|---|---|
| 合盖·游戏(收纳) | deck-lid | 0 | 0 | +0.00 |
| 合盖·游戏(收纳) | deck-phone | 0 | 0 | +1.92 |
| 合盖·游戏(收纳) | lid-cradle | 0 | 0 | +0.17 |
| 展开·游戏 | deck-lid | 110 | 0 | +0.24 |
| 展开·游戏 | deck-cradle | 110 | 0 | +6.77 |
| 展开·游戏 | deck-phone | 110 | 0 | +8.28 |
| 合盖·手机模式 | deck-phone | 0 | 180 | +8.77 |
| 合盖·手机模式 | deck-cradle | 0 | 180 | +3.92 |
| 合盖·手机模式 | lid-cradle | 0 | 180 | +0.16 |
| 翻转扫描 θ=110 | lid-cradle | 110 | 0 | +0.15 |
| 翻转扫描 θ=110 | lid-cradle | 110 | 10 | +0.16 |
| 翻转扫描 θ=110 | lid-cradle | 110 | 20 | +0.16 |
| 翻转扫描 θ=110 | lid-cradle | 110 | 30 | +0.16 |
| 翻转扫描 θ=110 | lid-cradle | 110 | 40 | +0.15 |
| 翻转扫描 θ=110 | lid-cradle | 110 | 50 | +0.16 |
| 翻转扫描 θ=110 | lid-cradle | 110 | 60 | +0.15 |
| 翻转扫描 θ=110 | lid-cradle | 110 | 70 | +0.16 |
| 翻转扫描 θ=110 | lid-cradle | 110 | 80 | +0.16 |
| 翻转扫描 θ=110 | lid-cradle | 110 | 90 | +0.16 |
| 翻转扫描 θ=110 | lid-cradle | 110 | 100 | +0.15 |
| 翻转扫描 θ=110 | lid-cradle | 110 | 110 | +0.16 |
| 翻转扫描 θ=110 | lid-cradle | 110 | 120 | +0.20 |
| 翻转扫描 θ=110 | lid-cradle | 110 | 130 | +0.16 |
| 翻转扫描 θ=110 | lid-cradle | 110 | 140 | +0.15 |
| 翻转扫描 θ=110 | lid-cradle | 110 | 150 | +0.15 |
| 翻转扫描 θ=110 | lid-cradle | 110 | 160 | +0.16 |
| 翻转扫描 θ=110 | lid-cradle | 110 | 170 | +0.15 |
| 翻转扫描 θ=110 | lid-cradle | 110 | 180 | +0.16 |
| 翻转扫描(全部件最坏) | lid-cradle | 110 | 0 | +0.15 |
| 手机模式合盖过程 | deck-phone | 30 | 180 | +9.68 |
| 手机模式合盖过程 | deck-phone | 60 | 180 | +11.81 |
| 手机模式合盖过程 | deck-phone | 90 | 180 | +9.51 |

结论：全部姿态无干涉 ✔

## 渲染图

- `out\ip12\render_closed_game.png` — 合盖 · 游戏收纳 (θ=0, φ=0)
- `out\ip12\render_open_game.png` — 展开 · 游戏中 (θ=110, φ=0)
- `out\ip12\render_open_game_back.png` — 展开 · 游戏中（后视，看铰链）
- `out\ip12\render_closed_phone.png` — 合盖 · 手机模式 (θ=0, φ=180)
- `out\ip12\render_switch_mid.png` — 换形态中间 (θ=110, φ=90)
- `out\ip12\render_switch_mid_side.png` — 换形态中间（侧视）
- `out\ip12\render_exploded.png` — 爆炸图：deck / lid / cradle / phone
- `out\ip12\part_deck.png` — 零件 deck
- `out\ip12\part_lid.png` — 零件 lid
- `out\ip12\part_cradle.png` — 零件 cradle
- `out\ip12\render_detail_axle.png` — 机构特写：托盘轴颈 + 棘轮定位
- `out\ip12\render_section_closed.png` — 剖视：合盖游戏位：三层夹心
- `out\ip12\render_section_phone.png` — 剖视：手机模式：手机翻到盖外侧
- `out\ip12\render_flip_sequence.png` — 托盘翻转过程 φ=0/45/90/135/180（θ=110 开盖状态）

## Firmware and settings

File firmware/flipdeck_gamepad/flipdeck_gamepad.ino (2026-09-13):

/* ============================================================================
 *  flipdeck 蓝牙手柄固件  (ESP32-S3 + 2 摇杆 + 11 按键)
 *  ---------------------------------------------------------------------------
 *  作用：把 flipdeck 底座里的摇杆和按键，伪装成一个标准 BLE HID 游戏手柄，
 *        iPhone / iPad / Android / PC 直接配对使用（iPhone 12 走蓝牙即可，无需 MFi）。
 *
 *  依赖（Arduino IDE）：
 *    1) 开发板支持：esp32 by Espressif  —— **请用 2.0.x（如 2.0.17）**，3.x 的 BLE API 变了可能编不过
 *    2) 库：ESP32 BLE Gamepad (lemmingDev)  —— 库管理器搜 "ESP32 BLE Gamepad"
 *
 *  烧录设置：Board = "ESP32S3 Dev Module"，USB CDC On Boot = Enabled，串口 115200
 * ==========================================================================*/

#include <BleGamepad.h>

// ============================== 配置区（照着改） ==============================

#define DEVICE_NAME        "flipdeck"   // 蓝牙里显示的名字
#define REPORT_HZ          100          // 上报频率 Hz
#define AXES_API           8            // 8 = 新版库 setAxes(8个参数)；6 = 旧版库(去掉 rudder)
#define REPORT_BATTERY     0            // 1 = 上报电量（需要接 VBAT 分压；老库若无此方法就保持 0）
#define DEBUG_SERIAL       0            // 1 = 串口打印摇杆原始值（标定用），正常玩时设 0
#define AUTO_CENTER_ON_BOOT 1           // 开机自动取摇杆中点（值越大越省事，也越依赖开机时手别碰摇杆）
#define INVERT_LY          1            // 左摇杆 Y 反向（一般都要 1）
#define INVERT_RY          1            // 右摇杆 Y 反向
#define INVERT_LX          0
#define INVERT_RX          0
#define DEADZONE_PCT       6            // 摇杆中心死区（%）
#define FILTER_SHIFT       2            // 摇杆低通滤波：2 = 4 次平均(推荐)，0 = 不滤波

// ---- 引脚（与 ELECTRONICS.md §7 引脚表一致，改线就改这里） ----
#define PIN_LX   1      // 左摇杆 X   (ADC1)
#define PIN_LY   2      // 左摇杆 Y   (ADC1)
#define PIN_RX   3      // 右摇杆 X   (ADC1)
#define PIN_RY   4      // 右摇杆 Y   (ADC1)

#define PIN_A    6
#define PIN_B    7
#define PIN_X    8
#define PIN_Y    9

#define PIN_DU  12      // 十字键 上
#define PIN_DD  13      // 十字键 下
#define PIN_DL  14      // 十字键 左
#define PIN_DR  15      // 十字键 右

#define PIN_START  16
#define PIN_SELECT 17
#define PIN_HOME   18
#define PIN_L1     21   // 左肩
#define PIN_R1     38   // 右肩
#define PIN_L3     39   // 左摇杆按下
#define PIN_R3     40   // 右摇杆按下

#define PIN_VBAT   11   // 电池电压采样（分压 100k/100k），不用就留空

// ---- 按键 -> HID 编号（想换布局只改这里） ----
// iOS/Android 上常见的对应关系：1=A 2=B 3=X 4=Y 5=L1 6=R1 7=L2 8=R2
//                              9=Select 10=Start 11=L3 12=R3 13=Home
#define BTN_A      1
#define BTN_B      2
#define BTN_X      3
#define BTN_Y      4
#define BTN_START  10
#define BTN_SELECT 9
#define BTN_HOME   13
#define BTN_L1     5
#define BTN_R1     6
#define BTN_L3     11
#define BTN_R3     12

// ---- 摇杆原始值范围（12bit ADC）----
// 如果 AUTO_CENTER_ON_BOOT=1，中点会自动测；上下限按你的模块实测微调
#define ADC_MIN_RAW   200
#define ADC_MAX_RAW   3900
#define ADC_CENTER_RAW 2048

#ifndef HAT_CENTERED
#define HAT_CENTERED   0
#define HAT_UP         1
#define HAT_UP_RIGHT   2
#define HAT_RIGHT      3
#define HAT_DOWN_RIGHT 4
#define HAT_DOWN       5
#define HAT_DOWN_LEFT  6
#define HAT_LEFT       7
#define HAT_UP_LEFT    8
#endif

// ============================== 实现 ==============================

BleGamepad bleGamepad(DEVICE_NAME, "flipdeck DIY", 100);

struct Axis {
  uint8_t pin;
  int center, lo, hi;
  bool invert;
  float filt;
};

Axis axLX = {PIN_LX, ADC_CENTER_RAW, ADC_MIN_RAW, ADC_MAX_RAW, INVERT_LX, 0};
Axis axLY = {PIN_LY, ADC_CENTER_RAW, ADC_MIN_RAW, ADC_MAX_RAW, INVERT_LY, 0};
Axis axRX = {PIN_RX, ADC_CENTER_RAW, ADC_MIN_RAW, ADC_MAX_RAW, INVERT_RX, 0};
Axis axRY = {PIN_RY, ADC_CENTER_RAW, ADC_MIN_RAW, ADC_MAX_RAW, INVERT_RY, 0};

struct Button { uint8_t pin; uint8_t hid; const char *name; };
Button buttons[] = {
  {PIN_A, BTN_A, "A"}, {PIN_B, BTN_B, "B"}, {PIN_X, BTN_X, "X"}, {PIN_Y, BTN_Y, "Y"},
  {PIN_L1, BTN_L1, "L1"}, {PIN_R1, BTN_R1, "R1"},
  {PIN_START, BTN_START, "Start"}, {PIN_SELECT, BTN_SELECT, "Select"}, {PIN_HOME, BTN_HOME, "Home"},
  {PIN_L3, BTN_L3, "L3"}, {PIN_R3, BTN_R3, "R3"},
};
const int N_BUTTONS = sizeof(buttons) / sizeof(buttons[0]);

// ---------------------------------------------------------------- 摇杆
void axisBegin(Axis &a) { pinMode(a.pin, INPUT); }

int axisRaw(Axis &a) {
  int v = analogRead(a.pin);
  if (FILTER_SHIFT > 0) {                       // 简单低通，压抖动
    a.filt += ((float)v - a.filt) / (float)(1 << FILTER_SHIFT);
    v = (int)(a.filt + 0.5f);
  }
  return v;
}

int axisValue(Axis &a, int raw) {
  int v;
  if (raw >= a.center) v = map(raw, a.center, a.hi, 0, 127);
  else                 v = map(raw, a.lo, a.center, -127, 0);
  v = constrain(v, -127, 127);
  if (abs(v) < (DEADZONE_PCT * 127 / 100)) v = 0;      // 死区
  if (a.invert) v = -v;
  return v;
}

void axisCalibrateCenter(Axis &a) {           // 开机取中点：手别碰摇杆
  long sum = 0;
  for (int i = 0; i < 32; i++) { sum += analogRead(a.pin); delay(2); }
  a.center = (int)(sum / 32);
  a.filt = a.center;
}

// ---------------------------------------------------------------- 按键
void buttonsBegin() {
  for (int i = 0; i < N_BUTTONS; i++) pinMode(buttons[i].pin, INPUT_PULLUP);
  pinMode(PIN_DU, INPUT_PULLUP); pinMode(PIN_DD, INPUT_PULLUP);
  pinMode(PIN_DL, INPUT_PULLUP); pinMode(PIN_DR, INPUT_PULLUP);
}

bool pressed(uint8_t pin) { return digitalRead(pin) == LOW; }   // 按键另一端接 GND

uint8_t readHat() {
  bool u = pressed(PIN_DU), d = pressed(PIN_DD), l = pressed(PIN_DL), r = pressed(PIN_DR);
  if (u && l) return HAT_UP_LEFT;
  if (u && r) return HAT_UP_RIGHT;
  if (d && l) return HAT_DOWN_LEFT;
  if (d && r) return HAT_DOWN_RIGHT;
  if (u) return HAT_UP;
  if (d) return HAT_DOWN;
  if (l) return HAT_LEFT;
  if (r) return HAT_RIGHT;
  return HAT_CENTERED;
}

#if REPORT_BATTERY
void reportBattery() {
  // 100k/100k 分压：VBAT 4.2V -> 2.1V -> ADC
  int raw = analogRead(PIN_VBAT);
  float v = raw * 3.3f / 4095.0f * 2.0f;
  int pct = (int)constrain((v - 3.30f) / (4.20f - 3.30f) * 100.0f, 0.0f, 100.0f);
  bleGamepad.setBatteryLevel((uint8_t)pct);
}
#endif

// ---------------------------------------------------------------- 主流程
void setup() {
  Serial.begin(115200);
  delay(200);
  Serial.println("\n[flipdeck] booting ...");

  analogReadResolution(12);
  axisBegin(axLX); axisBegin(axLY); axisBegin(axRX); axisBegin(axRY);
  buttonsBegin();

#if AUTO_CENTER_ON_BOOT
  Serial.println("[flipdeck] 标定摇杆中点：请松手");
  delay(400);
  axisCalibrateCenter(axLX); axisCalibrateCenter(axLY);
  axisCalibrateCenter(axRX); axisCalibrateCenter(axRY);
  Serial.printf("[flipdeck] center  L=(%d,%d)  R=(%d,%d)\n",
                axLX.center, axLY.center, axRX.center, axRY.center);
#endif

  bleGamepad.begin();
  Serial.printf("[flipdeck] BLE name = %s，等待配对…\n", DEVICE_NAME);
}

void loop() {
#if DEBUG_SERIAL
  static uint32_t tDbg = 0;
  if (millis() - tDbg > 200) {
    tDbg = millis();
    Serial.printf("raw LX=%4d LY=%4d RX=%4d RY=%4d | hat=%d | A=%d B=%d X=%d Y=%d\n",
                  analogRead(PIN_LX), analogRead(PIN_LY), analogRead(PIN_RX), analogRead(PIN_RY),
                  readHat(), pressed(PIN_A), pressed(PIN_B), pressed(PIN_X), pressed(PIN_Y));
  }
#endif

  static uint32_t tLast = 0;
  const uint32_t period = 1000 / REPORT_HZ;
  if (millis() - tLast < period) { delay(1); return; }
  tLast = millis();

  if (!bleGamepad.isConnected()) return;

  int lx = axisValue(axLX, axisRaw(axLX));
  int ly = axisValue(axLY, axisRaw(axLY));
  int rx = axisValue(axRX, axisRaw(axRX));
  int ry = axisValue(axRY, axisRaw(axRY));
  uint8_t hat = readHat();

#if AXES_API == 8
  bleGamepad.setAxes(lx, ly, rx, ry, 0, 0, 0, hat);
#else
  bleGamepad.setAxes(lx, ly, rx, ry, 0, 0, hat);
#endif
  // 如果你的库版本没有 setAxes，改成下面三行：
  //   bleGamepad.setLeftThumb(lx, ly);
  //   bleGamepad.setRightThumb(rx, ry);
  //   bleGamepad.setHat1(hat);

  for (int i = 0; i < N_BUTTONS; i++) {
    if (pressed(buttons[i].pin)) bleGamepad.press(buttons[i].hid);
    else                         bleGamepad.release(buttons[i].hid);
  }

#if REPORT_BATTERY
  static uint32_t tBat = 0;
  if (millis() - tBat > 10000) { tBat = millis(); reportBattery(); }
#endif
}

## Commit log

2026-09-13 flipdeck: phone-to-handheld flip case (dual-axis clamshell + 180-degree flip tray)
    - parametric SDF design (deck / lid / cradle), 9 print parts, all watertight
    - 13-pose interference checks + full 180-degree flip sweep: no collisions
    - iPhone 12 cradle; deck+lid are model-independent
    - ESP32-S3 BLE HID gamepad firmware
    - zero-dependency WebGL viewer with a keyboard-playable mini game (GitHub Pages)
    [cap_a.stl, cap_b.stl, cap_dpad.stl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]
2026-09-13 docs: add ORDER_KIT, GitHub Pages setup, progress/doc alignment
    - ORDER_KIT.md: print-vendor instructions + first-article checklist
    - make_docs.py + docs/ for GitHub Pages; LICENSE (MIT / CC BY 4.0)
    - README rewritten as a project front page; PROGRESS.md updated (repo + Pages links)
2026-09-13 slim + refine: 42.4mm closed (22.5mm daily without deck), finer hinge, playable racer
    CAD: deck 20->19mm, lid 16->15.1mm, plate 7->6.6mm, hinge barrel 16.4->14 dia with
    axis moved forward (4mm less overhang), tray axle boss 16->14.8 dia.
    Re-verified: 9 parts still watertight, all 13 pose checks still clear.
    Viewer: 3mm screen bezel with concentric rounded corners, fixed left-right mirror
    (which made character movement feel inverted), front 3/4 default camera framing,
    new pseudo-3D racing game, daily-mode button, params.json-driven constants.
    [cradle.stl, deck.stl, lid.stl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]
2026-09-13 viewer: replace confusing pseudo-3D racer with Tetris (d-pad) and Breakout (stick)
    - default camera now targets the screen center and looks nearly along the screen
    normal (was aimed at the body center, so the screen read as tilted away)
    - games: platformer (keep), Tetris (D-pad + Start), Breakout (analog stick)
    - fix prevDown snapshot timing so edge-triggered keys work
2026-09-13 feat: breakout ball physics fix + zero-backend leaderboard (issues -> Actions -> README)
    - breakout: outgoing angle now derived from paddle hit offset only (was inheriting
    the incoming vertical component, so the ball flattened out and drifted sideways);
    sub-stepped ball movement to stop tunneling; restored the lost-ball life handling
    - leaderboard: docs/leaderboard.json + LEADERBOARD.md + README injected block,
    built by .github/scripts/build_leaderboard.py from [SCORE] issues (selftest included)
    - workflow leaderboard.yml (issue events + nightly), issue form template
    - viewer: local bests in localStorage, 提交成绩 button (prefilled issue), Top10 panel
2026-09-13 chore(leaderboard): 更新各游戏 Top10 [skip ci]
2026-09-13 feat(cad+viewer): cradle rim so the phone nests both ways; +2 games; leaderboard on screen
    CAD: cradle gains a 7.4mm rim (0.7mm above the screen) with finger notches, so the phone
    is embedded in the tray at both phi=0 and phi=180 (no slab-stuck-on-the-back look) with no
    thickness change. Sweep radius 37.85mm vs 39mm bars. Fixed: wall_in not spanning the rim
    (made it a solid slab, 131 -> 64.8 cm3) and a 0.05mm sub-voxel sliver at the notches.
    Viewer: snake + flappy (5 games total), screen option that renders the live leaderboard,
    local bests for all five, leaderboard script/template extended.
    [cradle.stl]
2026-09-13 viewer: auto-framing so the whole device (incl. the button deck) is visible on load
    Compute the camera target/distance from the projected bounding boxes of every part at the
    current pose instead of hard-coded numbers (the old target sat on the screen centre, which
    pushed the deck out of frame). Also re-frames on pose buttons and on 视角复位.
    Verified headless with web/verify_framing.js: all 5 poses fully inside the frame.
2026-09-13 fix(viewer): TDZ crash (pendingFrames used before declaration) that made the page black
    The auto-framing patch assigned pendingFrames above its 'let' declaration, so the whole
    script threw on load and nothing rendered. Fixed, and added a headless smoke harness
    (web/verify_runtime.js) that runs the page JS against DOM/WebGL stubs, exercises all five
    games / leaderboard screen / pose sliders / submit button and counts drawArrays calls -
    it reproduced this exact crash before the fix.
2026-09-15 feat(modular): keyboard deck variant - swap the base to get a mini laptop for vibe-coding
    - hinge interface is now the module standard (pin bore, knuckle position, 19mm mating
    plane, magnets, gasket); swapping a base = pull the M4 pin, drop the other base in
    - new printable part deck_keyboard (160.0 cm3 / ~71 g / 6-8 h): replaces the control well
    with a bay for an off-the-shelf mini BLE keyboard module (150x60x7.5mm, own battery and
    charging port), so no new electronics are needed; key top sits 0.5mm below the rim,
    0.8mm lip at the front edge, 14x6 charge cutout in the left wall
    - poses/check_poses: keyboard-deck block (no contact with lid is expected, module sits on
    the bay floor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
    [deck_keyboard.stl, keyboard_module.stl]
2026-09-15 ci: gate every push on the verification chain, and stop docs/ from drifting
    - new `verify` workflow runs what used to be manual: check_poses (which already includes
    params.sanity), viewer matrix math vs poses.pose, the auto-framing check, the runtime
    smoke test (catches black-screen-class errors), and a docs-freshness job that reruns
    make_docs.py and fails if docs/ is behind web/
    - leaderboard workflow now also refreshes web/leaderboard.json and runs make_docs.py, so
    docs/LEADERBOARD.md and docs/leaderboard.json can no longer go stale after a bot run
    - resync the two copies that had already drifted (web/leaderboard.json, docs/LEADERBOARD.md)
2026-09-15 ci: bump actions to the node24 majors, note the new gate in PROGRESS
    - checkout@v5 / setup-python@v6 / setup-node@v5 (v4/v5 targets warned about node20)
    - PROGRESS 变更记录补上 verify workflow 与两处漂移修复

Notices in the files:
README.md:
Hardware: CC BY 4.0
